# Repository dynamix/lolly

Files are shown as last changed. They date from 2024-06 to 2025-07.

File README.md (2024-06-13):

# lolly
Who does not like a LOLLY!

⠀⠀⠀⠀⠀⠀⠀⠀⠀⠀⠀⠀⠀⠀⠀⠀⠀⠀⠀⠀⠀⠀⠀⠀⠀⠀⠀⠀⠀⠀
⠀⠀⠀⠀⠀⠀⠀⠀⠀⠀⠀⠀⠀⠀⣀⣤⡶⠾⠿⠿⠷⠶⣦⣄⡀⠀⠀⠀⠀⠀
⠀⠀⠀⠀⠀⠀⠀⠀⠀⠀⠀⠀⣠⡾⠋⣁⣤⣶⣾⣿⣶⣦⣄⠙⠻⣦⡀⠀⠀⠀
⠀⠀⠀⠀⠀⠀⠀⠀⠀⠀⠀⣼⠟⢀⣾⣿⠟⠋⣉⣉⡉⠛⢿⣿⣄⠙⣷⡀⠀⠀
⠀⠀⠀⠀⠀⠀⠀⠀⠀⠀⢰⡟⢀⣿⡿⠁⣴⣿⠿⠿⣿⣶⡀⠻⣿⣇⢸⣇⠀⠀
⠀⠀⠀⠀⠀⠀⠀⠀⠀⠀⢸⡇⢸⣿⡇⢸⣿⡇⠀⣦⠈⢿⣿⠀⢻⣿⠀⣿⠀⠀
⠀⠀⠀⠀⠀⠀⠀⠀⠀⠀⠘⣧⠈⣿⣷⡀⠻⣿⣿⡿⢀⣾⣿⠀⣼⣿⠀⡏⠀⠀
⠀⠀⠀⠀⠀⠀⠀⠀⠀⠀⠀⢻⣆⠘⢿⣿⣦⣤⣠⣤⣾⡿⠋⣰⣿⡟⠘⠀⠀⠀
⠀⠀⠀⠀⠀⠀⠀⠀⠀⠀⢀⣄⠙⢷⣄⡉⠛⠿⠿⠛⠋⣠⣴⣿⠟⠀⠀⠀⠀⠀
⠀⠀⠀⠀⠀⠀⠀⠀⢀⣴⣿⠟⠀⠀⠉⠛⠓⠶⠶⠶⠿⠟⠛⠁⠀⠀⠀⠀⠀⠀
⠀⠀⠀⠀⠀⠀⢀⣴⣿⠟⠁⠀⠀⠀⠀⠀⠀⠀⠀⠀⠀⠀⠀⠀⠀⠀⠀⠀⠀⠀
⠀⠀⠀⠀⠀⣠⣿⠟⠁⠀⠀⠀⠀⠀⠀⠀⠀⠀⠀⠀⠀⠀⠀⠀⠀⠀⠀⠀⠀⠀
⠀⠀⠀⣠⣾⡿⠋⠀⠀⠀⠀⠀⠀⠀⠀⠀⠀⠀⠀⠀⠀⠀⠀⠀⠀⠀⠀⠀⠀⠀
⠀⠀⣼⠿⠋⠀⠀⠀⠀⠀⠀⠀⠀⠀⠀⠀⠀⠀⠀⠀⠀⠀⠀⠀⠀⠀⠀⠀⠀⠀
⠀⠀⠀⠀⠀⠀⠀⠀⠀⠀⠀⠀⠀⠀⠀⠀⠀⠀⠀⠀⠀⠀⠀⠀⠀⠀⠀⠀⠀⠀

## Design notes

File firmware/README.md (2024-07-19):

# L O L L Y

⠀⠀⠀⠀⠀⠀⠀⠀⠀⠀⠀⠀⠀⠀⠀⠀⠀⠀⠀⠀⠀⠀⠀⠀⠀⠀⠀⠀⠀⠀
⠀⠀⠀⠀⠀⠀⠀⠀⠀⠀⠀⠀⠀⠀⣀⣤⡶⠾⠿⠿⠷⠶⣦⣄⡀⠀⠀⠀⠀⠀
⠀⠀⠀⠀⠀⠀⠀⠀⠀⠀⠀⠀⣠⡾⠋⣁⣤⣶⣾⣿⣶⣦⣄⠙⠻⣦⡀⠀⠀⠀
⠀⠀⠀⠀⠀⠀⠀⠀⠀⠀⠀⣼⠟⢀⣾⣿⠟⠋⣉⣉⡉⠛⢿⣿⣄⠙⣷⡀⠀⠀
⠀⠀⠀⠀⠀⠀⠀⠀⠀⠀⢰⡟⢀⣿⡿⠁⣴⣿⠿⠿⣿⣶⡀⠻⣿⣇⢸⣇⠀⠀
⠀⠀⠀⠀⠀⠀⠀⠀⠀⠀⢸⡇⢸⣿⡇⢸⣿⡇⠀⣦⠈⢿⣿⠀⢻⣿⠀⣿⠀⠀
⠀⠀⠀⠀⠀⠀⠀⠀⠀⠀⠘⣧⠈⣿⣷⡀⠻⣿⣿⡿⢀⣾⣿⠀⣼⣿⠀⡏⠀⠀
⠀⠀⠀⠀⠀⠀⠀⠀⠀⠀⠀⢻⣆⠘⢿⣿⣦⣤⣠⣤⣾⡿⠋⣰⣿⡟⠘⠀⠀⠀
⠀⠀⠀⠀⠀⠀⠀⠀⠀⠀⢀⣄⠙⢷⣄⡉⠛⠿⠿⠛⠋⣠⣴⣿⠟⠀⠀⠀⠀⠀
⠀⠀⠀⠀⠀⠀⠀⠀⢀⣴⣿⠟⠀⠀⠉⠛⠓⠶⠶⠶⠿⠟⠛⠁⠀⠀⠀⠀⠀⠀
⠀⠀⠀⠀⠀⠀⢀⣴⣿⠟⠁⠀⠀⠀⠀⠀⠀⠀⠀⠀⠀⠀⠀⠀⠀⠀⠀⠀⠀⠀
⠀⠀⠀⠀⠀⣠⣿⠟⠁⠀⠀⠀⠀⠀⠀⠀⠀⠀⠀⠀⠀⠀⠀⠀⠀⠀⠀⠀⠀⠀
⠀⠀⠀⣠⣾⡿⠋⠀⠀⠀⠀⠀⠀⠀⠀⠀⠀⠀⠀⠀⠀⠀⠀⠀⠀⠀⠀⠀⠀⠀
⠀⠀⣼⠿⠋⠀⠀⠀⠀⠀⠀⠀⠀⠀⠀⠀⠀⠀⠀⠀⠀⠀⠀⠀⠀⠀⠀⠀⠀⠀
⠀⠀⠀⠀⠀⠀⠀⠀⠀⠀⠀⠀⠀⠀⠀⠀⠀⠀⠀⠀⠀⠀⠀⠀⠀⠀⠀

Lick it! Get electroCUTEd!

## Prerequisites

- [Arduino 2.3.2](https://www.arduino.cc/en/Main/Software?)
- `brew install arduino-cli` might be enough
- [latest Teensyduino](https://www.pjrc.com/teensy/td_download.html)
  - add this to "Additional board manager URLs" in Arduino settings:
  - `https://www.pjrc.com/teensy/package_teensy_index.json`
- a Teensy 3.6
- a RaspperyPi Zero W (for over the air updates)

## Setup

Get the `teensy_loader_cli` available in the repo `firmware` directory:
```bash
cd firmware
brew install teensy_loader_cli
ln -s $(which teensy_loader_cli) ./teensy_loader_cli 
```

### Needed libraries

To make it easier - every lib including the Teensy core are in this repo :) 

**Important** for the potentiometer to work correctly, the Teensy Audio library needed to be edited
. Open `input_adc.cpp` (to be found in the Teensy audio library folder) and find the call to `analogReference(INTERNAL);` and comment it out. (See https://github.com/PaulStoffregen/Audio/blob/master/input_adc.cpp#L51)

# Simulator

Check out: https://wokwi.com/projects/403018840445060097

# Remark

The code base is in no way idiomatic C/C++ (i.e. directly including files without headers) or written to please the eye. :-)

# Build

```
make
```

# Deploy

Over the air deployment relies on:
- the PI is connected to the local network
- the PI and the Teensy are correctly connected
- the teensyloader is available on the PI

```
make deploy
```

# Serial port on Pi

TODO

# Ideas for effects

* animation going for inside to the outside
* circles from mid to edge rotating at different speeds with diff
* spirals controllable with knobs and buttons
* classic lolly spirals red and white with one arm or many
* Bitmap/GIF rendering! For a smily or a heart
* a pulsing heart
* color sparkels
* fire
* plasma
* bouncy balls
* rains
* audio wave form visualisation
* little particles going in a direction that start with very white light and fade after

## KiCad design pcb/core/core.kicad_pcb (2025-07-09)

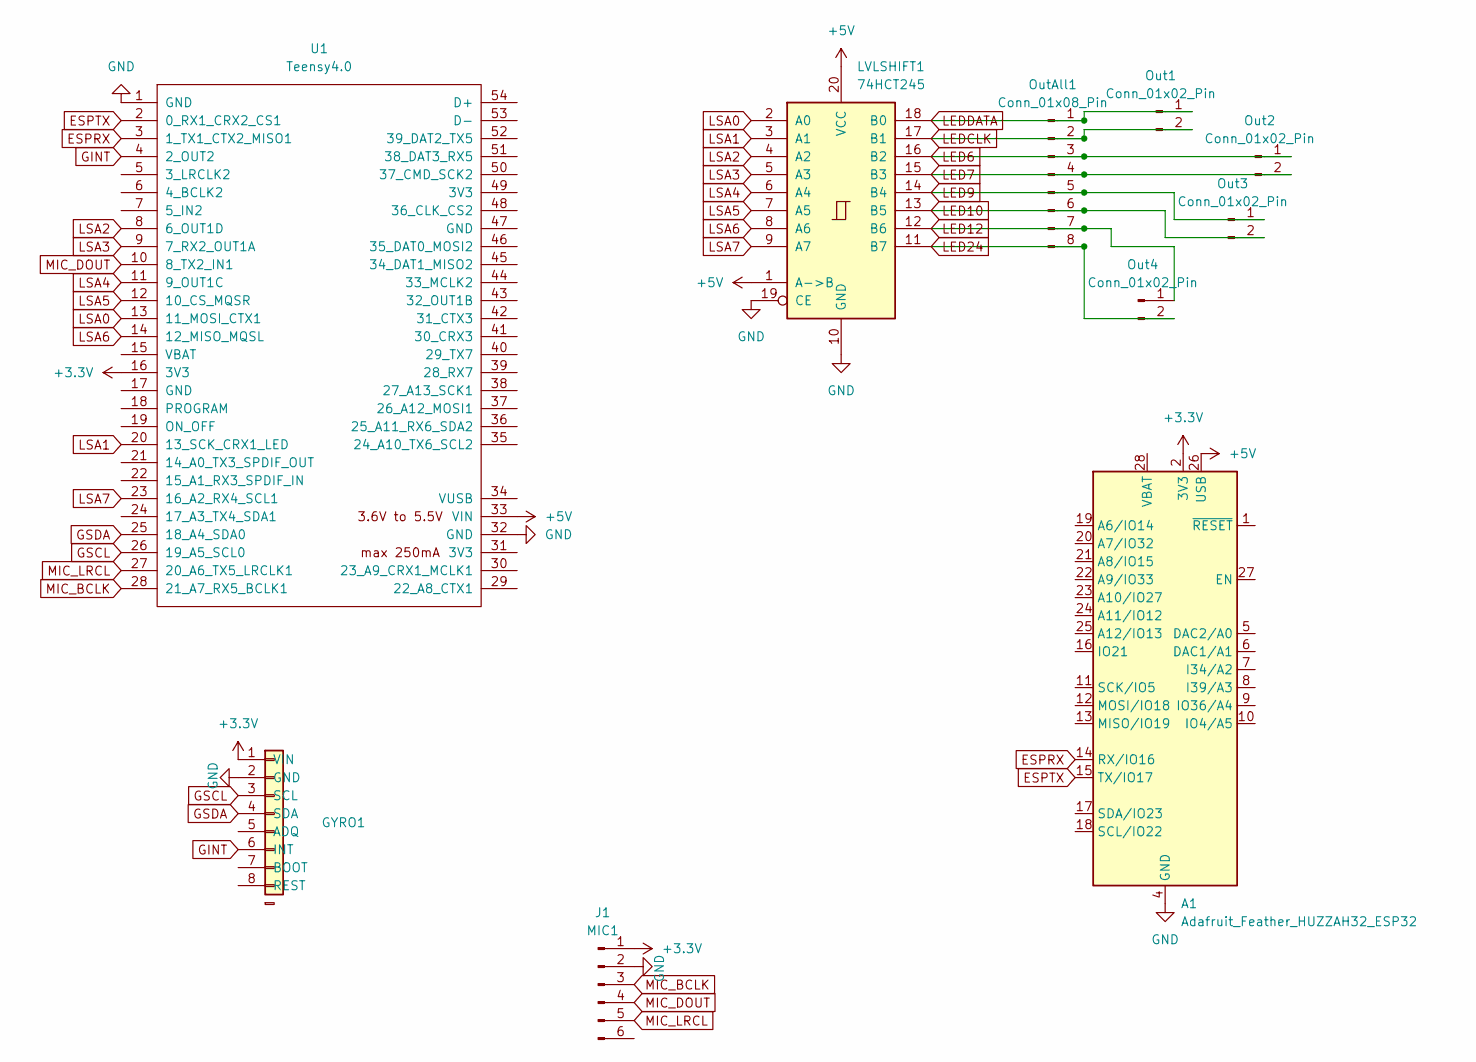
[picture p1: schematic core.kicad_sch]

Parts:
A1: Adafruit_Feather_HUZZAH32_ESP32; Adafruit_Feather
GYRO1: Conn_01x09; PinHeader_1x08_P2.54mm_Vertical
J1: MIC1; PinHeader_1x06_P2.54mm_Vertical
LVLSHIFT1: 74HCT245; SOIC-20W_7.5x12.8mm_P1.27mm
Out1, Out2, Out3, Out4: Conn_01x02_Pin; JST_PH_B2B-PH-K_1x02_P2.00mm_Vertical
OutAll1: Conn_01x08_Pin; PinHeader_1x08_P2.54mm_Vertical
U1: Teensy4.0; Teensy40

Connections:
+3.3V: A1.2 (3V3), GYRO1.1 (VIN), J1.1, U1.16 (3V3)
+5V: A1.26 (USB), LVLSHIFT1.1 (A->B), LVLSHIFT1.20 (VCC), U1.33 (VIN)
ESPRX: A1.14 (RX/IO16), U1.3 (1_TX1_CTX2_MISO1)
ESPTX: A1.15 (TX/IO17), U1.2 (0_RX1_CRX2_CS1)
GINT: GYRO1.6 (INT), U1.4 (2_OUT2)
GND: A1.4 (GND), GYRO1.2 (GND), J1.2, LVLSHIFT1.10 (GND), LVLSHIFT1.19 (CE), U1.1 (GND), U1.32 (GND)
GSCL: GYRO1.3 (SCL), U1.26 (19_A5_SCL0)
GSDA: GYRO1.4 (SDA), U1.25 (18_A4_SDA0)
LED6: LVLSHIFT1.16 (B2), Out2.1, OutAll1.3
LED7: LVLSHIFT1.15 (B3), Out2.2, OutAll1.4
LED9: LVLSHIFT1.14 (B4), Out3.1, OutAll1.5
LED10: LVLSHIFT1.13 (B5), Out3.2, OutAll1.6
LED12: LVLSHIFT1.12 (B6), Out4.1, OutAll1.7
LED24: LVLSHIFT1.11 (B7), Out4.2, OutAll1.8
LEDCLK: LVLSHIFT1.17 (B1), Out1.2, OutAll1.2
LEDDATA: LVLSHIFT1.18 (B0), Out1.1, OutAll1.1
LSA0: LVLSHIFT1.2 (A0), U1.13 (11_MOSI_CTX1)
LSA1: LVLSHIFT1.3 (A1), U1.20 (13_SCK_CRX1_LED)
LSA2: LVLSHIFT1.4 (A2), U1.8 (6_OUT1D)
LSA3: LVLSHIFT1.5 (A3), U1.9 (7_RX2_OUT1A)
LSA4: LVLSHIFT1.6 (A4), U1.11 (9_OUT1C)
LSA5: LVLSHIFT1.7 (A5), U1.12 (10_CS_MQSR)
LSA6: LVLSHIFT1.8 (A6), U1.14 (12_MISO_MQSL)
LSA7: LVLSHIFT1.9 (A7), U1.23 (16_A2_RX4_SCL1)
MIC_BCLK: J1.3, U1.28 (21_A7_RX5_BCLK1)
MIC_DOUT: J1.4, U1.10 (8_TX2_IN1)
MIC_LRCL: J1.5, U1.27 (20_A6_TX5_LRCLK1)

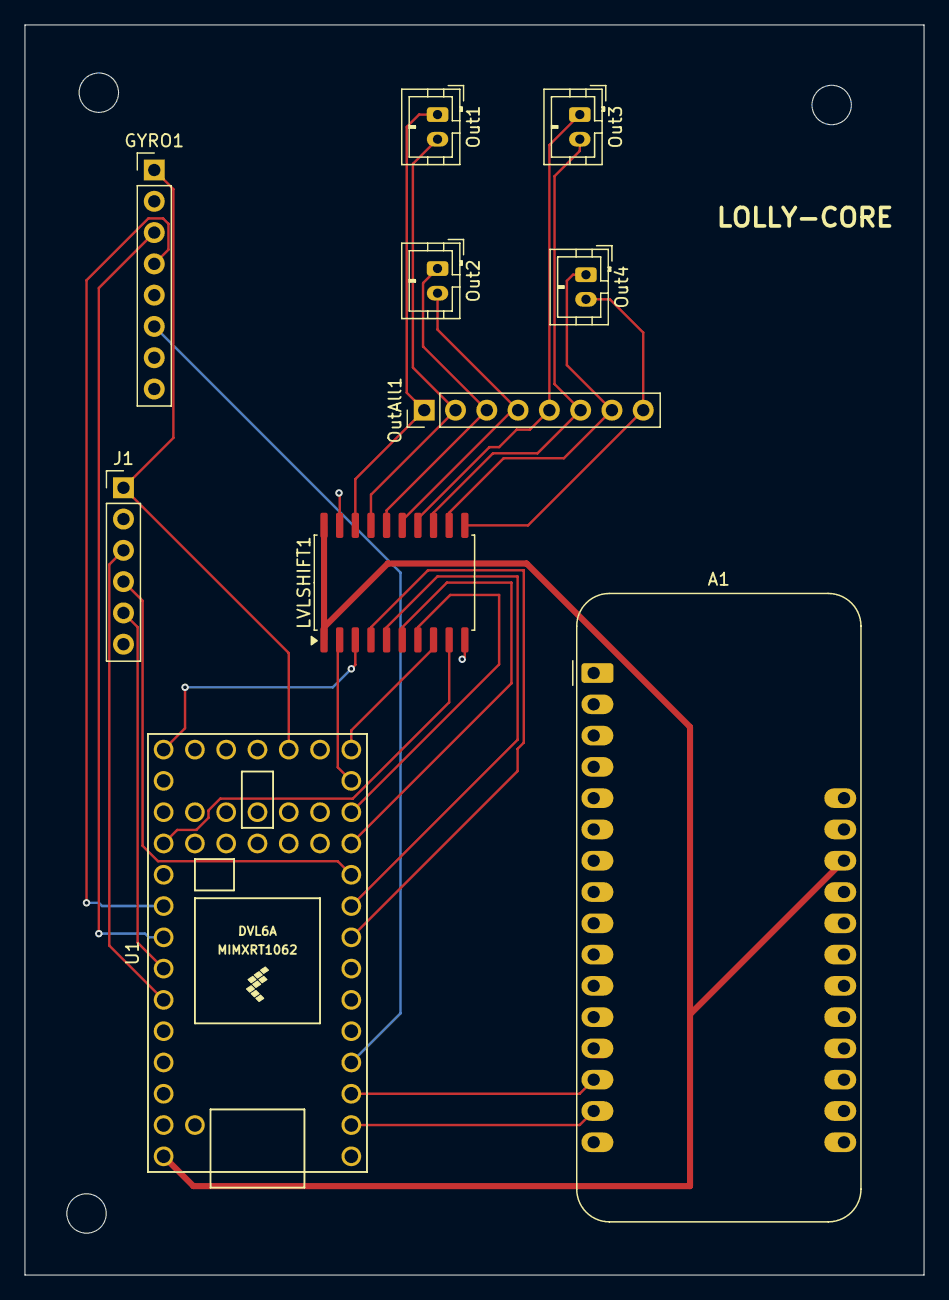
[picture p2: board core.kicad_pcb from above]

Board: 2 copper layers, 73.0 x 101.5 mm, 10 parts (0 on the bottom side), 27 nets.

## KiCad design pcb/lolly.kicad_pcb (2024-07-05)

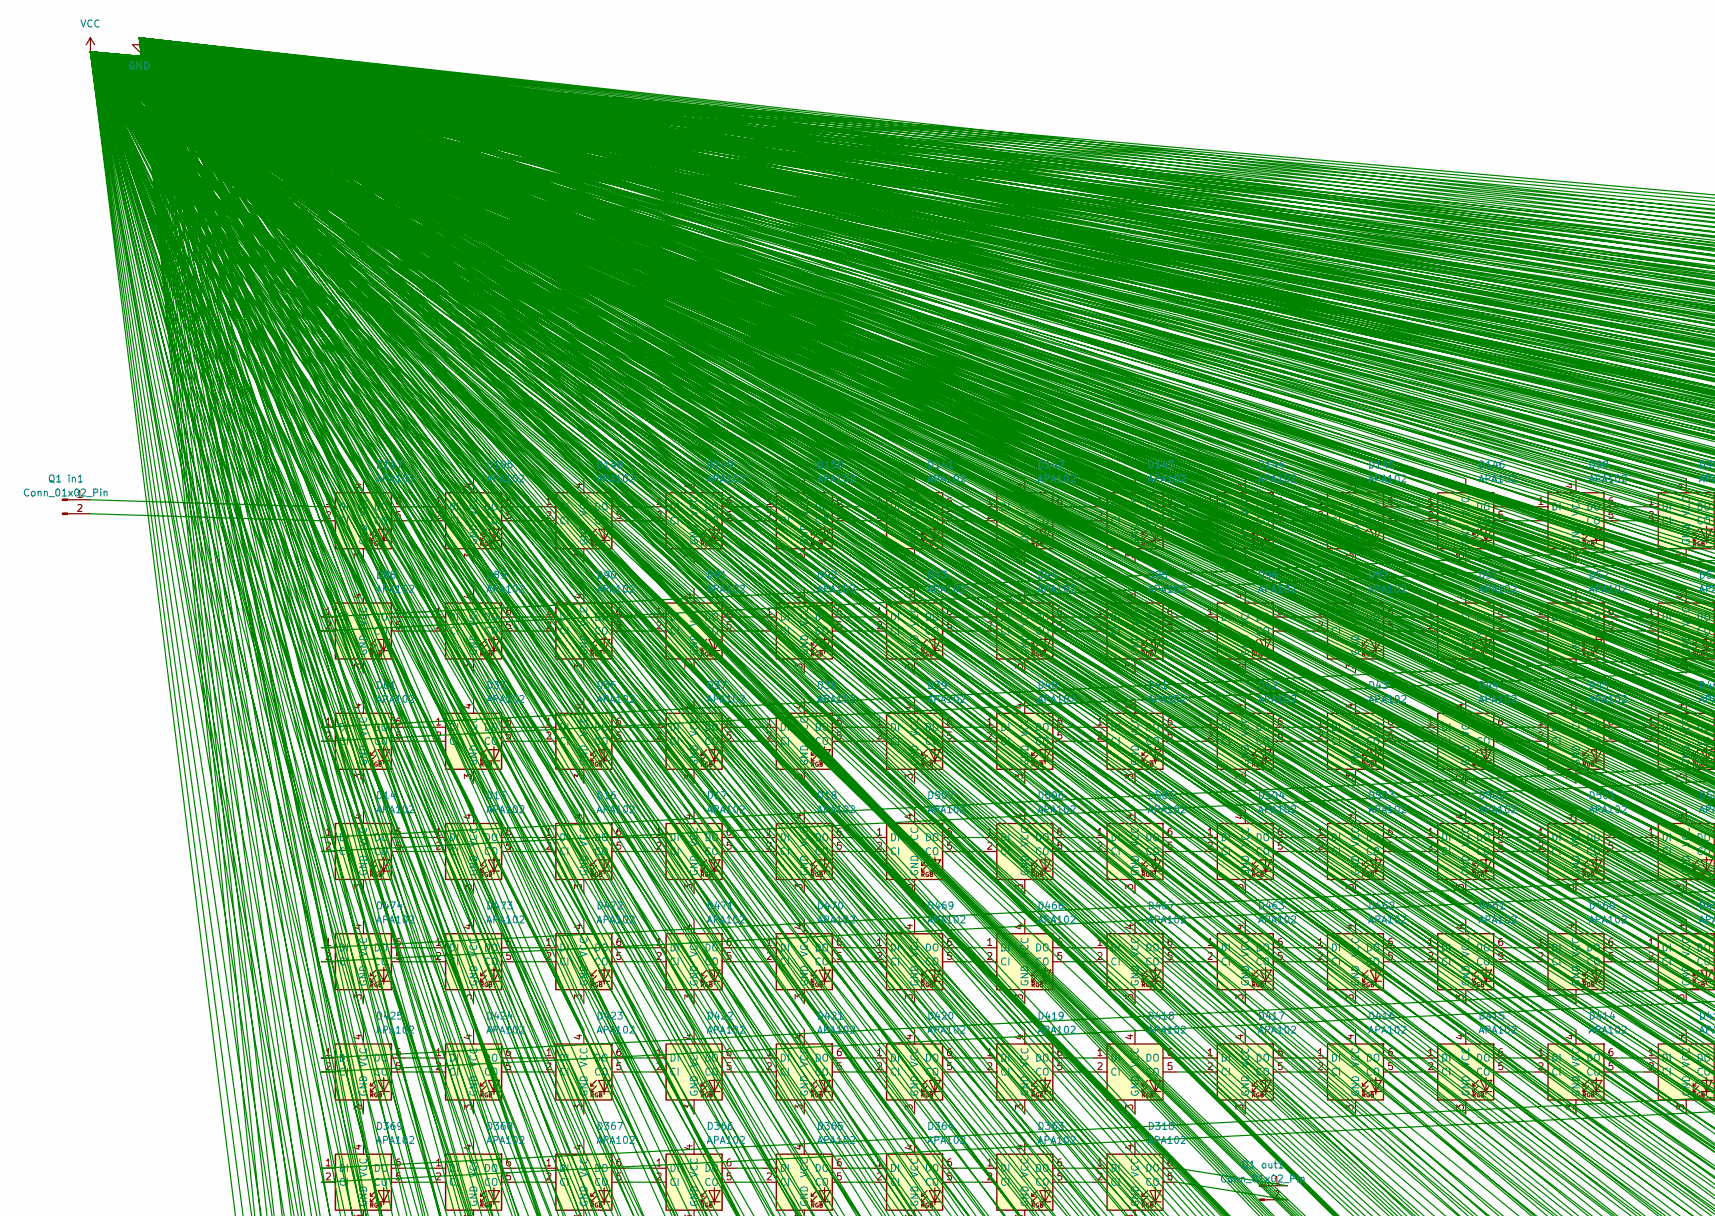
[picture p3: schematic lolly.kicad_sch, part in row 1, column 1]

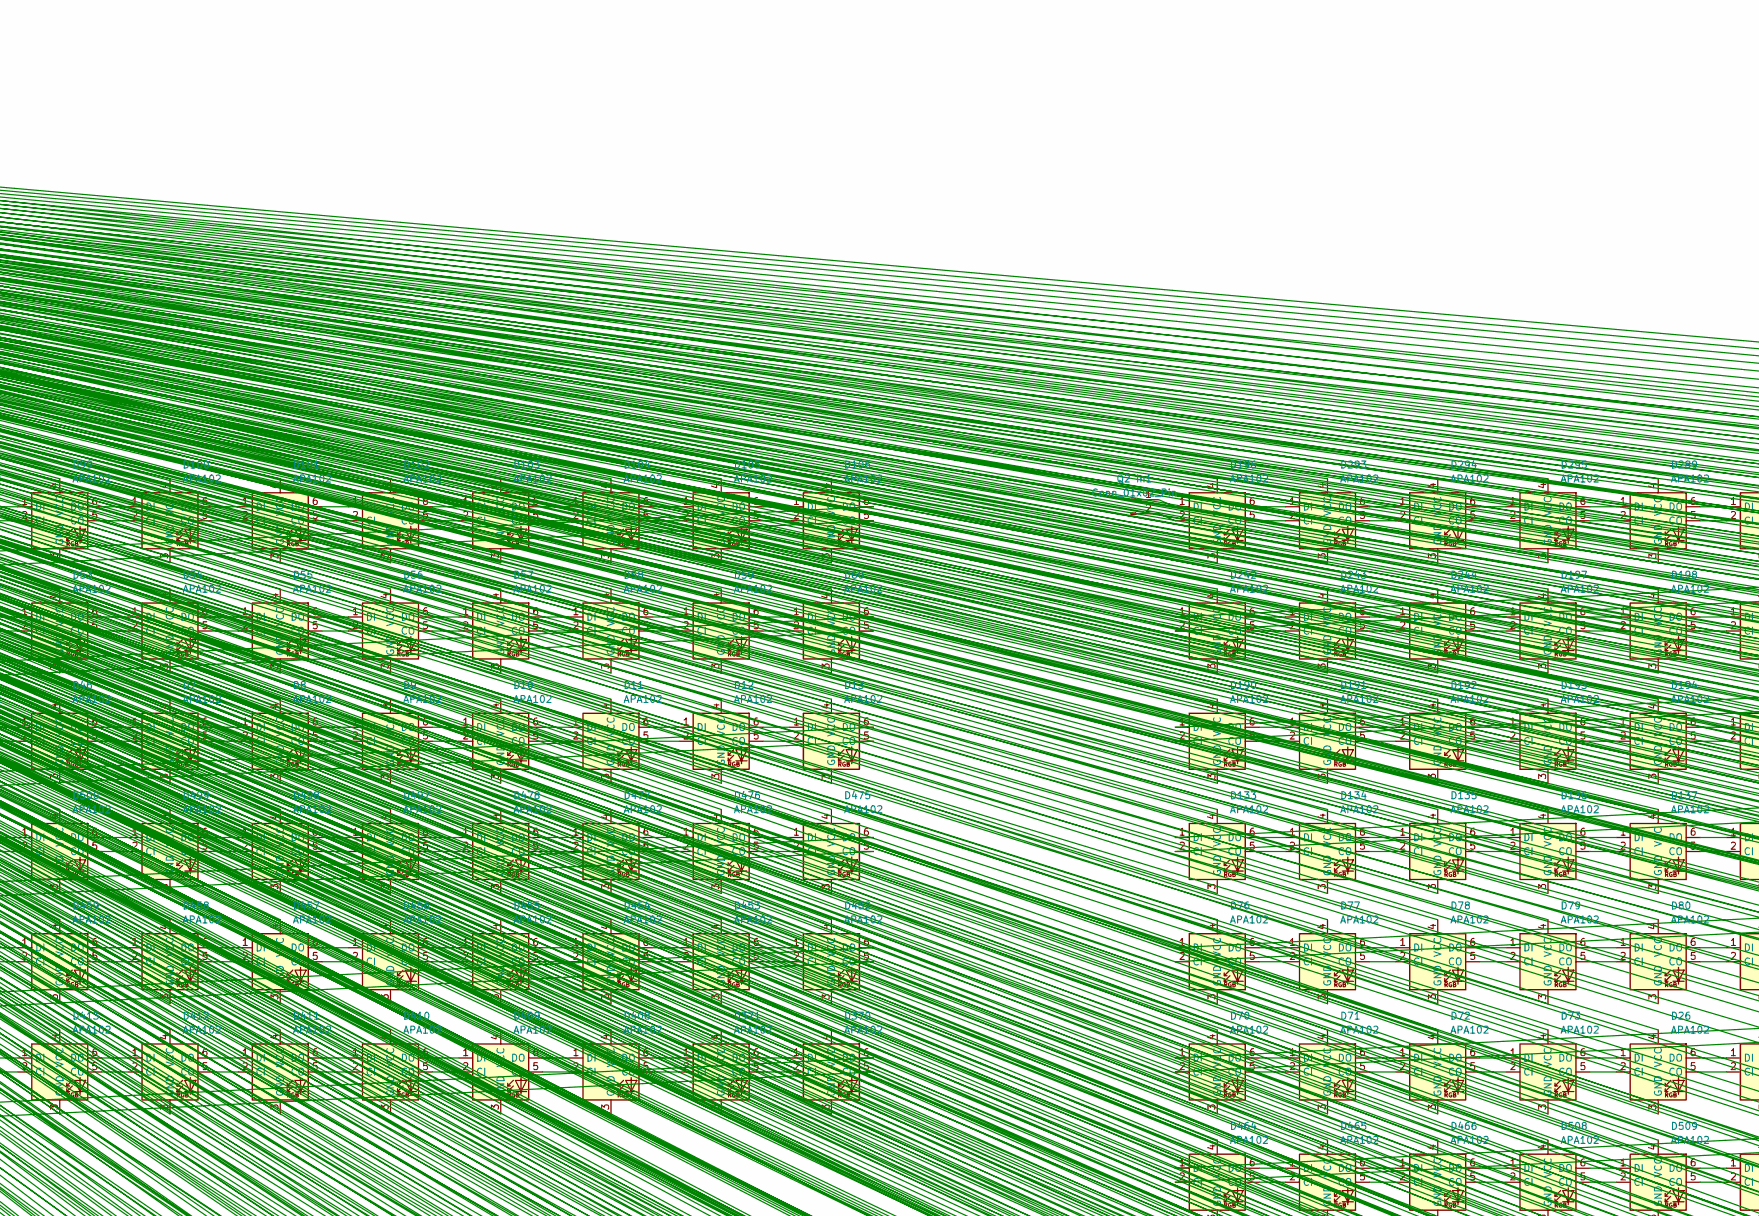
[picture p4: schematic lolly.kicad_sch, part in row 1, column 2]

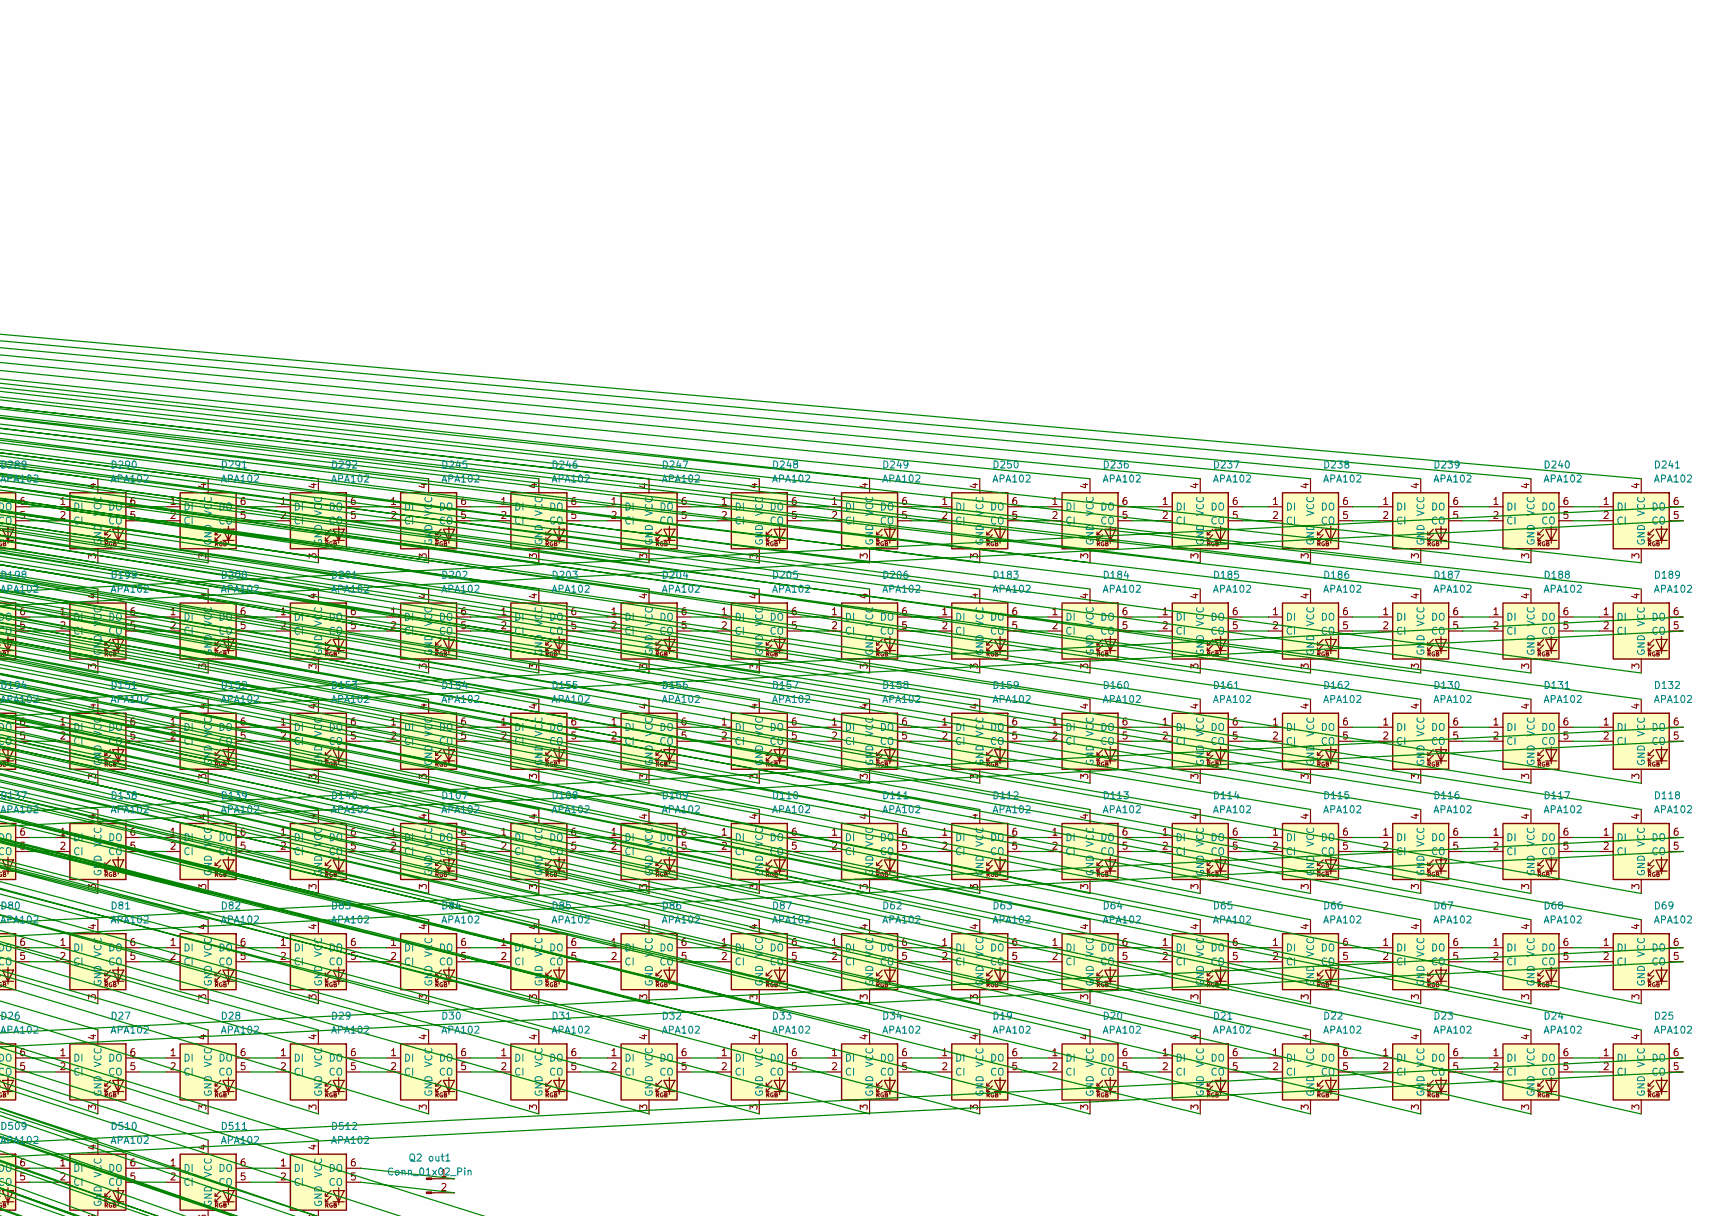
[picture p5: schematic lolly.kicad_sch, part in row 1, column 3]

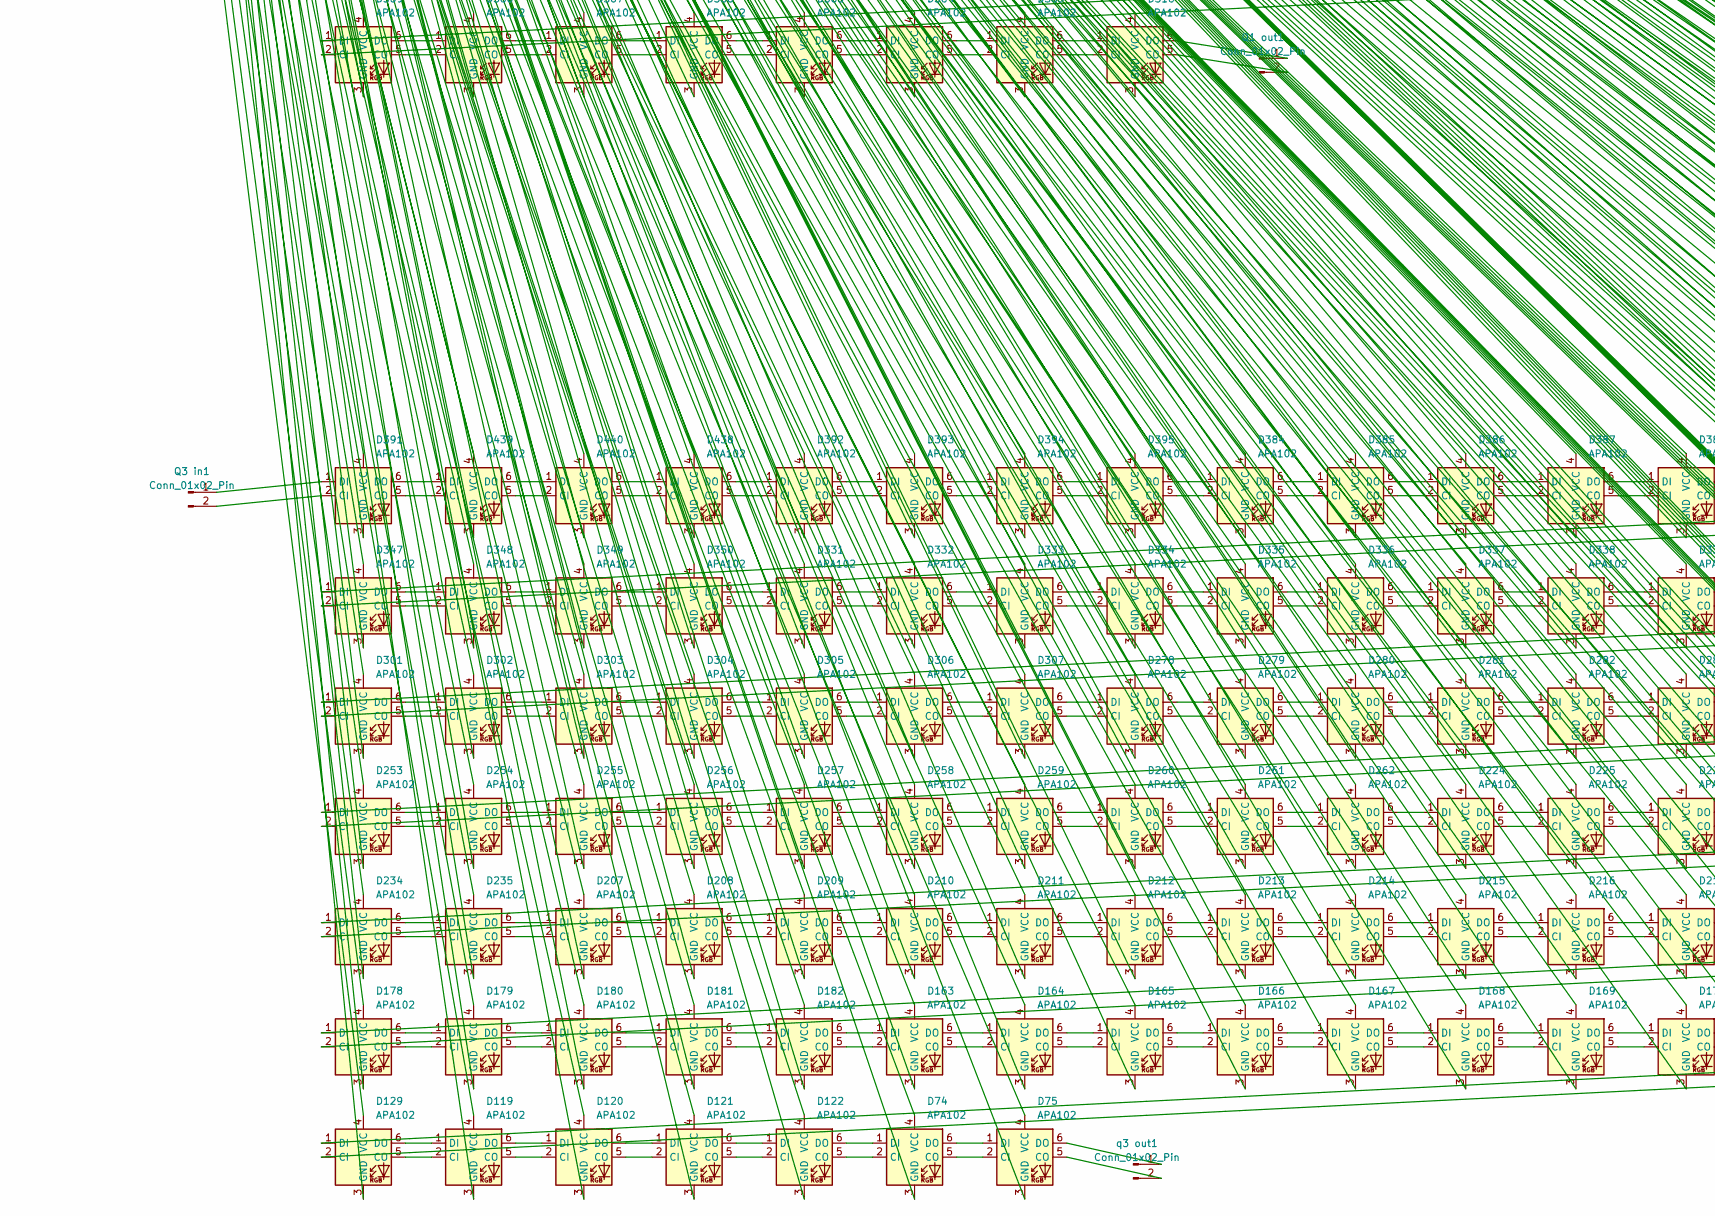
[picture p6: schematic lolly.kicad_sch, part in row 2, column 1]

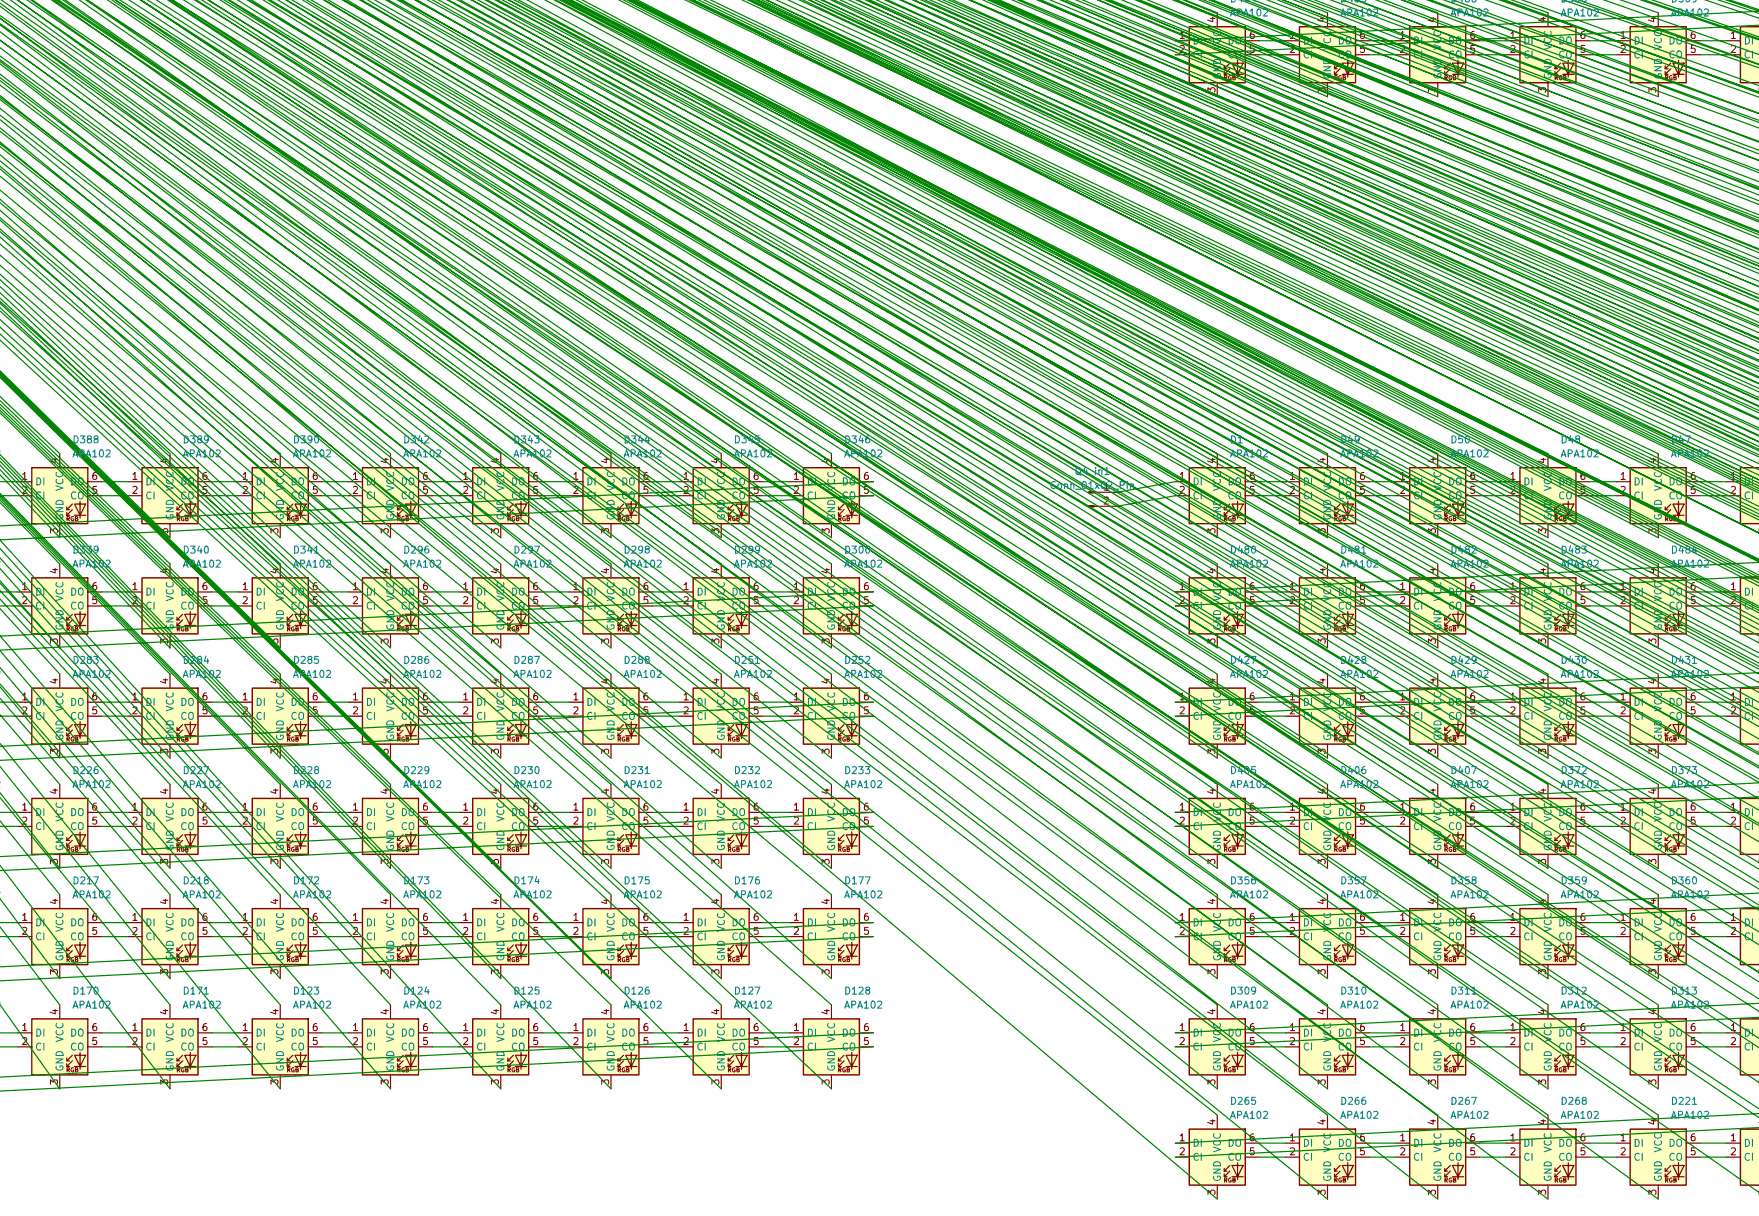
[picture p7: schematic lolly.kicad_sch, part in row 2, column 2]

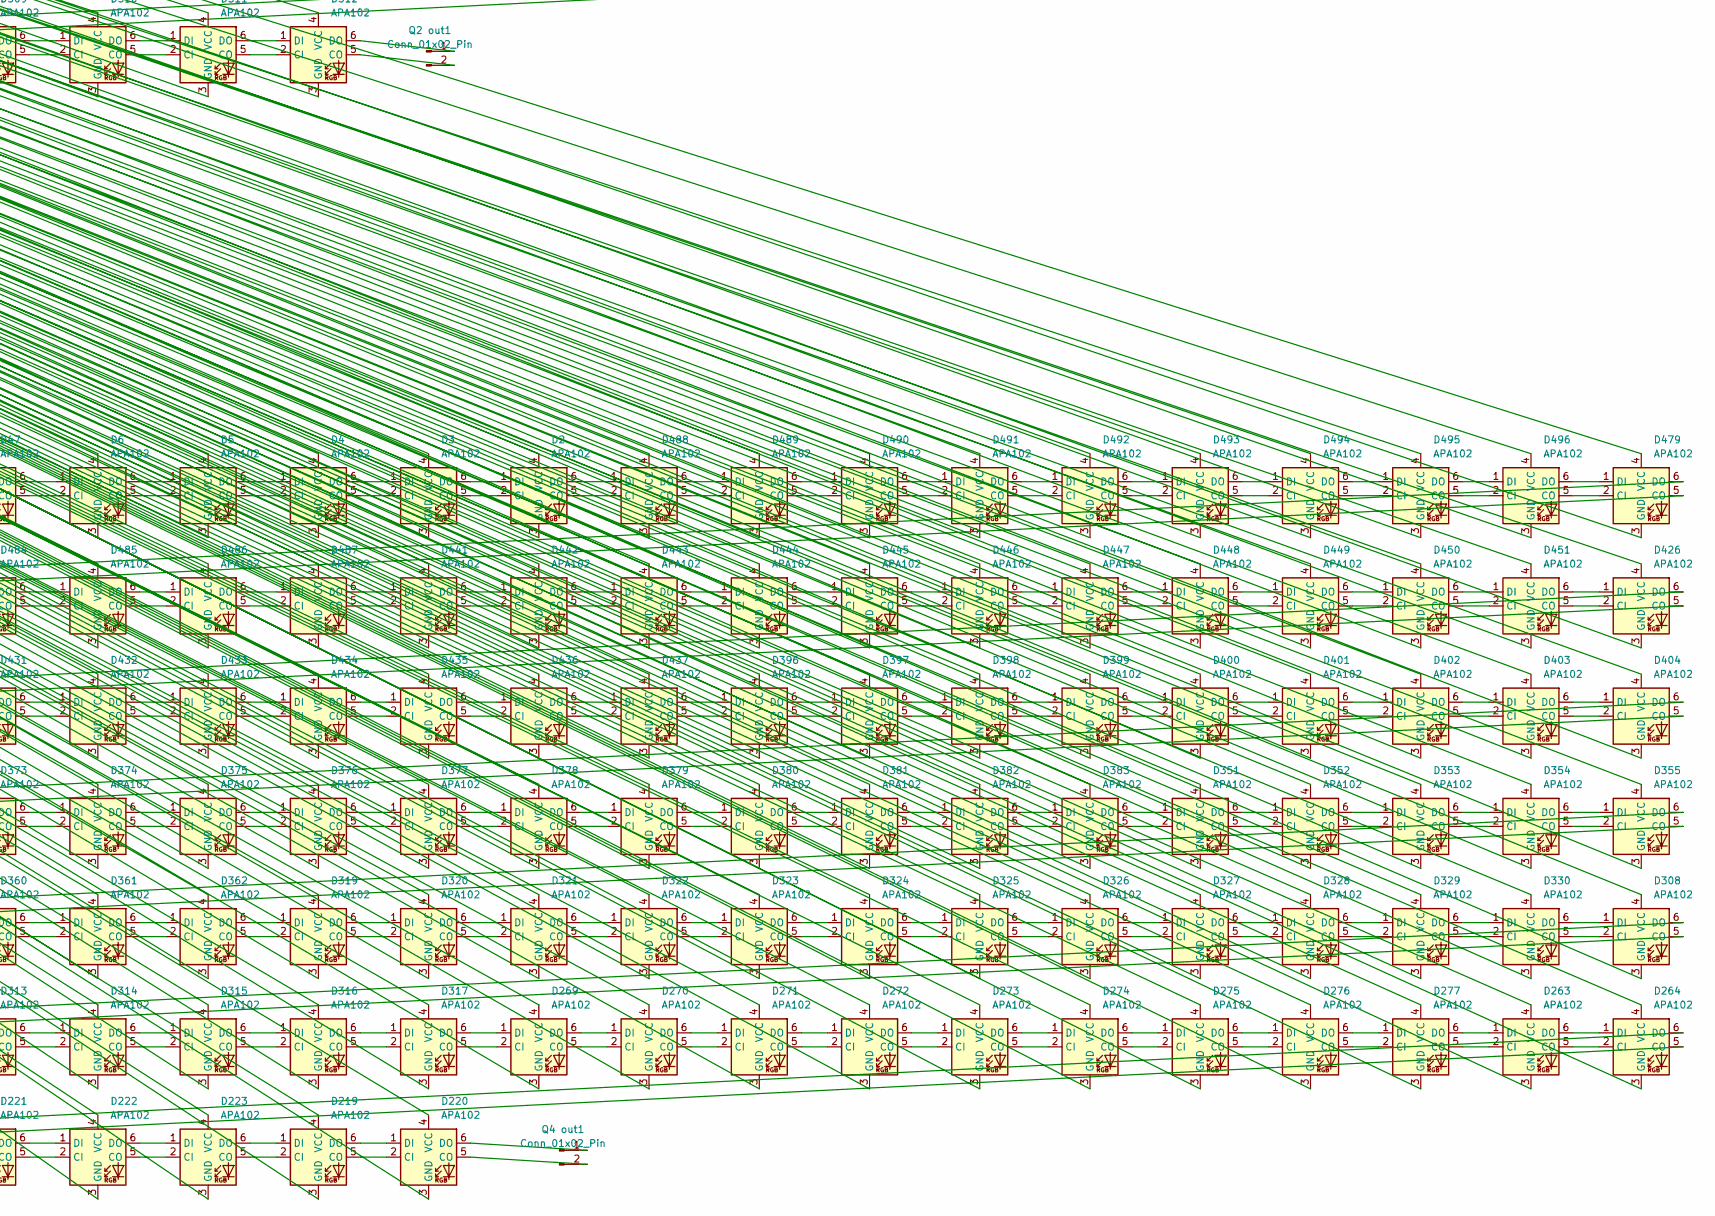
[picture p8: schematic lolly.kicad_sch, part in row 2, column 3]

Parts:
D1, D2, D3, D4, D5, D6, D7, D8, D9, D10, D11, D12, D13, D14, D15, D16, D17, D18, D19, D20, D21, D22, D23, D24, D25, D26, D27, D28, D29, D30, D31, D32, D33, D34, D35, D36, D37, D38, D39, D40, D41, D42, D43, D44, D45, D46, D47, D48, D49, D50, D51, D52, D53, D54, D55, D56, D57, D58, D59, D60, D61, D62, D63, D64, D65, D66, D67, D68, D69, D70, D71, D72, D73, D74, D75, D76, D77, D78, D79, D80, D81, D82, D83, D84, D85, D86, D87, D88, D89, D90, D91, D92, D93, D94, D95, D96, D97, D98, D99, D100, D101, D102, D103, D104, D105, D106, D107, D108, D109, D110, D111, D112, D113, D114, D115, D116, D117, D118, D119, D120, D121, D122, D123, D124, D125, D126, D127, D128, D129, D130, D131, D132, D133, D134, D135, D136, D137, D138, D139, D140, D141, D142, D143, D144, D145, D146, D147, D148, D149, D150, D151, D152, D153, D154, D155, D156, D157, D158, D159, D160, D161, D162, D163, D164, D165, D166, D167, D168, D169, D170, D171, D172, D173, D174, D175, D176, D177, D178, D179, D180, D181, D182, D183, D184, D185, D186, D187, D188, D189, D190, D191, D192, D193, D194, D195, D196, D197, D198, D199, D200, D201, D202, D203, D204, D205, D206, D207, D208, D209, D210, D211, D212, D213, D214, D215, D216, D217, D218, D219, D220, D221, D222, D223, D224, D225, D226, D227, D228, D229, D230, D231, D232, D233, D234, D235, D236, D237, D238, D239, D240, D241, D242, D243, D244, D245, D246, D247, D248, D249, D250, D251, D252, D253, D254, D255, D256, D257, D258, D259, D260, D261, D262, D263, D264, D265, D266, D267, D268, D269, D270, D271, D272, D273, D274, D275, D276, D277, D278, D279, D280, D281, D282, D283, D284, D285, D286, D287, D288, D289, D290, D291, D292, D293, D294, D295, D296, D297, D298, D299, D300, D301, D302, D303, D304, D305, D306, D307, D308, D309, D310, D311, D312, D313, D314, D315, D316, D317, D318, D319, D320, D321, D322, D323, D324, D325, D326, D327, D328, D329, D330, D331, D332, D333, D334, D335, D336, D337, D338, D339, D340, D341, D342, D343, D344, D345, D346, D347, D348, D349, D350, D351, D352, D353, D354, D355, D356, D357, D358, D359, D360, D361, D362, D363, D364, D365, D366, D367, D368, D369, D370, D371, D372, D373, D374, D375, D376, D377, D378, D379, D380, D381, D382, D383, D384, D385, D386, D387, D388, D389, D390, D391, D392, D393, D394, D395, D396, D397, D398, D399, D400, D401, D402, D403, D404, D405, D406, D407, D408, D409, D410, D411, D412, D413, D414, D415, D416, D417, D418, D419, D420, D421, D422, D423, D424, D425, D426, D427, D428, D429, D430, D431, D432, D433, D434, D435, D436, D437, D438, D439, D440, D441, D442, D443, D444, D445, D446, D447, D448, D449, D450, D451, D452, D453, D454, D455, D456, D457, D458, D459, D460, D461, D462, D463, D464, D465, D466, D467, D468, D469, D470, D471, D472, D473, D474, D475, D476, D477, D478, D479, D480, D481, D482, D483, D484, D485, D486, D487, D488, D489, D490, D491, D492, D493, D494, D495, D496, D497, D498, D499, D500, D501, D502, D503, D504, D505, D506, D507, D508, D509, D510, D511, D512: APA102; LED_RGB_5050-6
Q1 in1, Q1 out1, Q2 in1, Q2 out1, Q3 in1, Q4 in1, Q4 out1: Conn_01x02_Pin; JST_PH_B2B-PH-K_1x02_P2.00mm_Vertical
q3 out1: Conn_01x02_Pin; JST_PH_B2B-PH-K_1x02_P2.00mm_Vertical

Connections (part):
GND: D1.3 (GND), D2.3 (GND), D3.3 (GND), D4.3 (GND), D5.3 (GND), D6.3 (GND), D7.3 (GND), D8.3 (GND), D9.3 (GND), D10.3 (GND), D11.3 (GND), D12.3 (GND), D13.3 (GND), D14.3 (GND), D15.3 (GND), D16.3 (GND), D17.3 (GND), D18.3 (GND), D19.3 (GND), D20.3 (GND), D21.3 (GND), D22.3 (GND), D23.3 (GND), D24.3 (GND), D25.3 (GND), D26.3 (GND), D27.3 (GND), D28.3 (GND), D29.3 (GND), D30.3 (GND), D31.3 (GND), D32.3 (GND), D33.3 (GND), D34.3 (GND), D35.3 (GND), D36.3 (GND), D37.3 (GND), D38.3 (GND), D39.3 (GND), D40.3 (GND), D41.3 (GND), D42.3 (GND), D43.3 (GND), D44.3 (GND), D45.3 (GND), D46.3 (GND), D47.3 (GND), D48.3 (GND), D49.3 (GND), D50.3 (GND), D51.3 (GND), D52.3 (GND), D53.3 (GND), D54.3 (GND), D55.3 (GND), D56.3 (GND), D57.3 (GND), D58.3 (GND), D59.3 (GND), D60.3 (GND), D61.3 (GND), D62.3 (GND), D63.3 (GND), D64.3 (GND), D65.3 (GND), D66.3 (GND), D67.3 (GND), D68.3 (GND), D69.3 (GND), D70.3 (GND), D71.3 (GND), D72.3 (GND), D73.3 (GND), D74.3 (GND), D75.3 (GND), D76.3 (GND), D77.3 (GND), D78.3 (GND), D79.3 (GND), D80.3 (GND)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; also elsewhere on the board
unnamed: D1.2 (CI), Q4 in1.2
unnamed: D1.5 (CO), D49.2 (CI)
unnamed: D1.1 (DI), Q4 in1.1
unnamed: D1.6 (DO), D49.1 (DI)
unnamed: D2.2 (CI), D3.5 (CO)
unnamed: D2.5 (CO), D488.2 (CI)
unnamed: D2.1 (DI), D3.6 (DO)
unnamed: D2.6 (DO), D488.1 (DI)
unnamed: D3.2 (CI), D4.5 (CO)
unnamed: D3.1 (DI), D4.6 (DO)
unnamed: D4.2 (CI), D5.5 (CO)
unnamed: D4.1 (DI), D5.6 (DO)
unnamed: D5.2 (CI), D6.5 (CO)
unnamed: D5.1 (DI), D6.6 (DO)
unnamed: D7.5 (CO), D8.2 (CI)
unnamed: D7.6 (DO), D8.1 (DI)
unnamed: D8.5 (CO), D9.2 (CI)
unnamed: D8.6 (DO), D9.1 (DI)
unnamed: D9.5 (CO), D10.2 (CI)
unnamed: D10.5 (CO), D11.2 (CI)
unnamed: D9.6 (DO), D10.1 (DI)
unnamed: D10.6 (DO), D11.1 (DI)
unnamed: D11.5 (CO), D12.2 (CI)
unnamed: D11.6 (DO), D12.1 (DI)
unnamed: D12.5 (CO), D13.2 (CI)
unnamed: D12.6 (DO), D13.1 (DI)
unnamed: D13.5 (CO), D14.2 (CI)
unnamed: D13.6 (DO), D14.1 (DI)
unnamed: D14.5 (CO), D15.2 (CI)
unnamed: D14.6 (DO), D15.1 (DI)
unnamed: D15.5 (CO), D16.2 (CI)
unnamed: D15.6 (DO), D16.1 (DI)
unnamed: D16.5 (CO), D17.2 (CI)
unnamed: D16.6 (DO), D17.1 (DI)
unnamed: D17.5 (CO), D18.2 (CI)
unnamed: D17.6 (DO), D18.1 (DI)
unnamed: D18.5 (CO), D507.2 (CI)
unnamed: D18.6 (DO), D507.1 (DI)
unnamed: D19.2 (CI), D34.5 (CO)
unnamed: D19.5 (CO), D20.2 (CI)
unnamed: D19.1 (DI), D34.6 (DO)
unnamed: D19.6 (DO), D20.1 (DI)
unnamed: D20.5 (CO), D21.2 (CI)
unnamed: D20.6 (DO), D21.1 (DI)
unnamed: D21.5 (CO), D22.2 (CI)
unnamed: D21.6 (DO), D22.1 (DI)
unnamed: D22.5 (CO), D23.2 (CI)
unnamed: D22.6 (DO), D23.1 (DI)
unnamed: D23.5 (CO), D24.2 (CI)
unnamed: D23.6 (DO), D24.1 (DI)
unnamed: D24.5 (CO), D25.2 (CI)
unnamed: D24.6 (DO), D25.1 (DI)
unnamed: D25.5 (CO), D464.2 (CI)
unnamed: D25.6 (DO), D464.1 (DI)
unnamed: D26.2 (CI), D73.5 (CO)
unnamed: D26.5 (CO), D27.2 (CI)
unnamed: D26.1 (DI), D73.6 (DO)
unnamed: D26.6 (DO), D27.1 (DI)
unnamed: D27.5 (CO), D28.2 (CI)
unnamed: D27.6 (DO), D28.1 (DI)
unnamed: D28.5 (CO), D29.2 (CI)
unnamed: D28.6 (DO), D29.1 (DI)
unnamed: D29.5 (CO), D30.2 (CI)
unnamed: D29.6 (DO), D30.1 (DI)
unnamed: D30.5 (CO), D31.2 (CI)
unnamed: D30.6 (DO), D31.1 (DI)
unnamed: D31.5 (CO), D32.2 (CI)
unnamed: D31.6 (DO), D32.1 (DI)
unnamed: D32.5 (CO), D33.2 (CI)
unnamed: D32.6 (DO), D33.1 (DI)
unnamed: D33.5 (CO), D34.2 (CI)
unnamed: D33.6 (DO), D34.1 (DI)
unnamed: D35.2 (CI), D61.5 (CO)
unnamed: D35.5 (CO), D36.2 (CI)
unnamed: D35.1 (DI), D61.6 (DO)
unnamed: D35.6 (DO), D36.1 (DI)
unnamed: D36.5 (CO), D37.2 (CI)
unnamed: D36.6 (DO), D37.1 (DI)
unnamed: D37.5 (CO), D38.2 (CI)
unnamed: D37.6 (DO), D38.1 (DI)
unnamed: D38.5 (CO), D39.2 (CI)
unnamed: D38.6 (DO), D39.1 (DI)
unnamed: D39.5 (CO), D40.2 (CI)
unnamed: D39.6 (DO), D40.1 (DI)
unnamed: D40.5 (CO), D41.2 (CI)
unnamed: D40.6 (DO), D41.1 (DI)
unnamed: D41.5 (CO), D42.2 (CI)
unnamed: D41.6 (DO), D42.1 (DI)
unnamed: D42.5 (CO), D43.2 (CI)
unnamed: D42.6 (DO), D43.1 (DI)
unnamed: D43.5 (CO), D44.2 (CI)
unnamed: D43.6 (DO), D44.1 (DI)
unnamed: D44.5 (CO), D45.2 (CI)
unnamed: D44.6 (DO), D45.1 (DI)
unnamed: D45.5 (CO), D46.2 (CI)
unnamed: D45.6 (DO), D46.1 (DI)
unnamed: D7.2 (CI), D46.5 (CO)
unnamed: D7.1 (DI), D46.6 (DO)
unnamed: D47.2 (CI), D48.5 (CO)
unnamed: D6.2 (CI), D47.5 (CO)
unnamed: D47.1 (DI), D48.6 (DO)
unnamed: D6.1 (DI), D47.6 (DO)
unnamed: D48.2 (CI), D50.5 (CO)
unnamed: D48.1 (DI), D50.6 (DO)
unnamed: D49.5 (CO), D50.2 (CI)
unnamed: D49.6 (DO), D50.1 (DI)
unnamed: D51.2 (CI), D97.5 (CO)
unnamed: D51.5 (CO), D52.2 (CI)
unnamed: D51.1 (DI), D97.6 (DO)
unnamed: D51.6 (DO), D52.1 (DI)
unnamed: D52.5 (CO), D53.2 (CI)
unnamed: D52.6 (DO), D53.1 (DI)
unnamed: D53.5 (CO), D54.2 (CI)
unnamed: D53.6 (DO), D54.1 (DI)
unnamed: D54.5 (CO), D55.2 (CI)
unnamed: D54.6 (DO), D55.1 (DI)
unnamed: D55.5 (CO), D56.2 (CI)
unnamed: D55.6 (DO), D56.1 (DI)
unnamed: D56.5 (CO), D57.2 (CI)
unnamed: D56.6 (DO), D57.1 (DI)
unnamed: D57.5 (CO), D58.2 (CI)
unnamed: D57.6 (DO), D58.1 (DI)
unnamed: D58.5 (CO), D59.2 (CI)
unnamed: D58.6 (DO), D59.1 (DI)
unnamed: D59.5 (CO), D60.2 (CI)
unnamed: D59.6 (DO), D60.1 (DI)
unnamed: D60.5 (CO), D61.2 (CI)
unnamed: D60.6 (DO), D61.1 (DI)
unnamed: D62.2 (CI), D87.5 (CO)
unnamed: D62.5 (CO), D63.2 (CI)
unnamed: D62.1 (DI), D87.6 (DO)
unnamed: D62.6 (DO), D63.1 (DI)
unnamed: D63.5 (CO), D64.2 (CI)
unnamed: D63.6 (DO), D64.1 (DI)
unnamed: D64.5 (CO), D65.2 (CI)
unnamed: D64.6 (DO), D65.1 (DI)
unnamed: D65.5 (CO), D66.2 (CI)
unnamed: D65.6 (DO), D66.1 (DI)
unnamed: D66.5 (CO), D67.2 (CI)
unnamed: D66.6 (DO), D67.1 (DI)
unnamed: D67.5 (CO), D68.2 (CI)
unnamed: D67.6 (DO), D68.1 (DI)
unnamed: D68.5 (CO), D69.2 (CI)
unnamed: D68.6 (DO), D69.1 (DI)
unnamed: D69.5 (CO), D70.2 (CI)
unnamed: D69.6 (DO), D70.1 (DI)
unnamed: D70.5 (CO), D71.2 (CI)
unnamed: D70.6 (DO), D71.1 (DI)
unnamed: D71.5 (CO), D72.2 (CI)
unnamed: D71.6 (DO), D72.1 (DI)
unnamed: D72.5 (CO), D73.2 (CI)
unnamed: D72.6 (DO), D73.1 (DI)
unnamed: D74.5 (CO), D75.2 (CI)
unnamed: D74.6 (DO), D75.1 (DI)
unnamed: D75.5 (CO), q3 out1.2
unnamed: D75.6 (DO), q3 out1.1
unnamed: D76.5 (CO), D77.2 (CI)
unnamed: D76.6 (DO), D77.1 (DI)
unnamed: D77.5 (CO), D78.2 (CI)
unnamed: D77.6 (DO), D78.1 (DI)
unnamed: D78.5 (CO), D79.2 (CI)
unnamed: D78.6 (DO), D79.1 (DI)
unnamed: D79.5 (CO), D80.2 (CI)
unnamed: D79.6 (DO), D80.1 (DI)
unnamed: D80.5 (CO), D81.2 (CI)
unnamed: D80.6 (DO), D81.1 (DI)
unnamed: D81.5 (CO), D82.2 (CI)
unnamed: D81.6 (DO), D82.1 (DI)
unnamed: D82.5 (CO), D83.2 (CI)
unnamed: D82.6 (DO), D83.1 (DI)
unnamed: D83.5 (CO), D84.2 (CI)
unnamed: D83.6 (DO), D84.1 (DI)
unnamed: D84.5 (CO), D85.2 (CI)
unnamed: D84.6 (DO), D85.1 (DI)
unnamed: D85.5 (CO), D86.2 (CI)
unnamed: D85.6 (DO), D86.1 (DI)
unnamed: D86.5 (CO), D87.2 (CI)
unnamed: D86.6 (DO), D87.1 (DI)
unnamed: D88.5 (CO), D89.2 (CI)
unnamed: D88.6 (DO), D89.1 (DI)
unnamed: D89.5 (CO), D90.2 (CI)
unnamed: D89.6 (DO), D90.1 (DI)
unnamed: D90.5 (CO), D91.2 (CI)
unnamed: D90.6 (DO), D91.1 (DI)
unnamed: D91.5 (CO), D92.2 (CI)
unnamed: D91.6 (DO), D92.1 (DI)
unnamed: D92.5 (CO), D93.2 (CI)
unnamed: D92.6 (DO), D93.1 (DI)
unnamed: D93.5 (CO), D94.2 (CI)
unnamed: D93.6 (DO), D94.1 (DI)
unnamed: D94.5 (CO), D95.2 (CI)
unnamed: D94.6 (DO), D95.1 (DI)
unnamed: D95.5 (CO), D96.2 (CI)
unnamed: D95.6 (DO), D96.1 (DI)
unnamed: D96.5 (CO), D97.2 (CI)
unnamed: D96.6 (DO), D97.1 (DI)
unnamed: D98.5 (CO), D99.2 (CI)
unnamed: D98.6 (DO), D99.1 (DI)
unnamed: D99.5 (CO), D100.2 (CI)
unnamed: D100.5 (CO), D101.2 (CI)
unnamed: D99.6 (DO), D100.1 (DI)
unnamed: D100.6 (DO), D101.1 (DI)
unnamed: D101.5 (CO), D102.2 (CI)
unnamed: D101.6 (DO), D102.1 (DI)
unnamed: D102.5 (CO), D103.2 (CI)
unnamed: D102.6 (DO), D103.1 (DI)
unnamed: D103.5 (CO), D104.2 (CI)
unnamed: D103.6 (DO), D104.1 (DI)
unnamed: D104.5 (CO), D105.2 (CI)
unnamed: D104.6 (DO), D105.1 (DI)
unnamed: D105.5 (CO), D106.2 (CI)
unnamed: D105.6 (DO), D106.1 (DI)
unnamed: D88.2 (CI), D106.5 (CO)
unnamed: D88.1 (DI), D106.6 (DO)
unnamed: D107.2 (CI), D140.5 (CO)
unnamed: D107.5 (CO), D108.2 (CI)
unnamed: D107.1 (DI), D140.6 (DO)
unnamed: D107.6 (DO), D108.1 (DI)
unnamed: D108.5 (CO), D109.2 (CI)
unnamed: D108.6 (DO), D109.1 (DI)
unnamed: D109.5 (CO), D110.2 (CI)
unnamed: D109.6 (DO), D110.1 (DI)
unnamed: D110.5 (CO), D111.2 (CI)
unnamed: D110.6 (DO), D111.1 (DI)
unnamed: D111.5 (CO), D112.2 (CI)
unnamed: D111.6 (DO), D112.1 (DI)
unnamed: D112.5 (CO), D113.2 (CI)
unnamed: D112.6 (DO), D113.1 (DI)
unnamed: D113.5 (CO), D114.2 (CI)
unnamed: D113.6 (DO), D114.1 (DI)
unnamed: D114.5 (CO), D115.2 (CI)
unnamed: D114.6 (DO), D115.1 (DI)
unnamed: D115.5 (CO), D116.2 (CI)
unnamed: D115.6 (DO), D116.1 (DI)
unnamed: D116.5 (CO), D117.2 (CI)
unnamed: D116.6 (DO), D117.1 (DI)
unnamed: D117.5 (CO), D118.2 (CI)
unnamed: D117.6 (DO), D118.1 (DI)
unnamed: D76.2 (CI), D118.5 (CO)
unnamed: D76.1 (DI), D118.6 (DO)
unnamed: D119.2 (CI), D129.5 (CO)
unnamed: D119.5 (CO), D120.2 (CI)
unnamed: D119.1 (DI), D129.6 (DO)
unnamed: D119.6 (DO), D120.1 (DI)
unnamed: D120.5 (CO), D121.2 (CI)
unnamed: D120.6 (DO), D121.1 (DI)
unnamed: D121.5 (CO), D122.2 (CI)
unnamed: D121.6 (DO), D122.1 (DI)
unnamed: D74.2 (CI), D122.5 (CO)
unnamed: D74.1 (DI), D122.6 (DO)
unnamed: D123.2 (CI), D171.5 (CO)
unnamed: D123.5 (CO), D124.2 (CI)
unnamed: D123.1 (DI), D171.6 (DO)
unnamed: D123.6 (DO), D124.1 (DI)
unnamed: D124.5 (CO), D125.2 (CI)
unnamed: D124.6 (DO), D125.1 (DI)
unnamed: D125.5 (CO), D126.2 (CI)
unnamed: D125.6 (DO), D126.1 (DI)
unnamed: D126.5 (CO), D127.2 (CI)
unnamed: D126.6 (DO), D127.1 (DI)
unnamed: D127.5 (CO), D128.2 (CI)
unnamed: D127.6 (DO), D128.1 (DI)
unnamed: D128.5 (CO), D129.2 (CI)
unnamed: D128.6 (DO), D129.1 (DI)
unnamed: D130.2 (CI), D162.5 (CO)
unnamed: D130.5 (CO), D131.2 (CI)
unnamed: D130.1 (DI), D162.6 (DO)
unnamed: D130.6 (DO), D131.1 (DI)
unnamed: D131.5 (CO), D132.2 (CI)
unnamed: D131.6 (DO), D132.1 (DI)
unnamed: D132.5 (CO), D133.2 (CI)
unnamed: D132.6 (DO), D133.1 (DI)
unnamed: D133.5 (CO), D134.2 (CI)
unnamed: D133.6 (DO), D134.1 (DI)
unnamed: D134.5 (CO), D135.2 (CI)
unnamed: D134.6 (DO), D135.1 (DI)
unnamed: D135.5 (CO), D136.2 (CI)
unnamed: D135.6 (DO), D136.1 (DI)
unnamed: D136.5 (CO), D137.2 (CI)
unnamed: D136.6 (DO), D137.1 (DI)
unnamed: D137.5 (CO), D138.2 (CI)
unnamed: D137.6 (DO), D138.1 (DI)
unnamed: D138.5 (CO), D139.2 (CI)
unnamed: D138.6 (DO), D139.1 (DI)
unnamed: D139.5 (CO), D140.2 (CI)
unnamed: D139.6 (DO), D140.1 (DI)
unnamed: D141.2 (CI), D150.5 (CO)
unnamed: D141.5 (CO), D142.2 (CI)
unnamed: D141.1 (DI), D150.6 (DO)
unnamed: D141.6 (DO), D142.1 (DI)
unnamed: D142.5 (CO), D143.2 (CI)
unnamed: D142.6 (DO), D143.1 (DI)
unnamed: D143.5 (CO), D144.2 (CI)
unnamed: D143.6 (DO), D144.1 (DI)
unnamed: D144.5 (CO), D145.2 (CI)
unnamed: D144.6 (DO), D145.1 (DI)
unnamed: D145.5 (CO), D146.2 (CI)
unnamed: D145.6 (DO), D146.1 (DI)
unnamed: D98.2 (CI), D146.5 (CO)
unnamed: D98.1 (DI), D146.6 (DO)
unnamed: D147.2 (CI), Q1 in1.2
unnamed: D147.5 (CO), D195.2 (CI)
unnamed: D147.1 (DI), Q1 in1.1
unnamed: D147.6 (DO), D195.1 (DI)
unnamed: D148.2 (CI), D195.5 (CO)
unnamed: D148.5 (CO), D149.2 (CI)
unnamed: D148.1 (DI), D195.6 (DO)
unnamed: D148.6 (DO), D149.1 (DI)
unnamed: D149.5 (CO), D150.2 (CI)
unnamed: D149.6 (DO), D150.1 (DI)
unnamed: D151.2 (CI), D194.5 (CO)
unnamed: D151.5 (CO), D152.2 (CI)
unnamed: D151.1 (DI), D194.6 (DO)
unnamed: D151.6 (DO), D152.1 (DI)
unnamed: D152.5 (CO), D153.2 (CI)
unnamed: D152.6 (DO), D153.1 (DI)
unnamed: D153.5 (CO), D154.2 (CI)
unnamed: D153.6 (DO), D154.1 (DI)
unnamed: D154.5 (CO), D155.2 (CI)
unnamed: D154.6 (DO), D155.1 (DI)
unnamed: D155.5 (CO), D156.2 (CI)
unnamed: D155.6 (DO), D156.1 (DI)
unnamed: D156.5 (CO), D157.2 (CI)
unnamed: D156.6 (DO), D157.1 (DI)
unnamed: D157.5 (CO), D158.2 (CI)
unnamed: D157.6 (DO), D158.1 (DI)
unnamed: D158.5 (CO), D159.2 (CI)
unnamed: D158.6 (DO), D159.1 (DI)
unnamed: D159.5 (CO), D160.2 (CI)
unnamed: D159.6 (DO), D160.1 (DI)
unnamed: D160.5 (CO), D161.2 (CI)
unnamed: D160.6 (DO), D161.1 (DI)
unnamed: D161.5 (CO), D162.2 (CI)
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

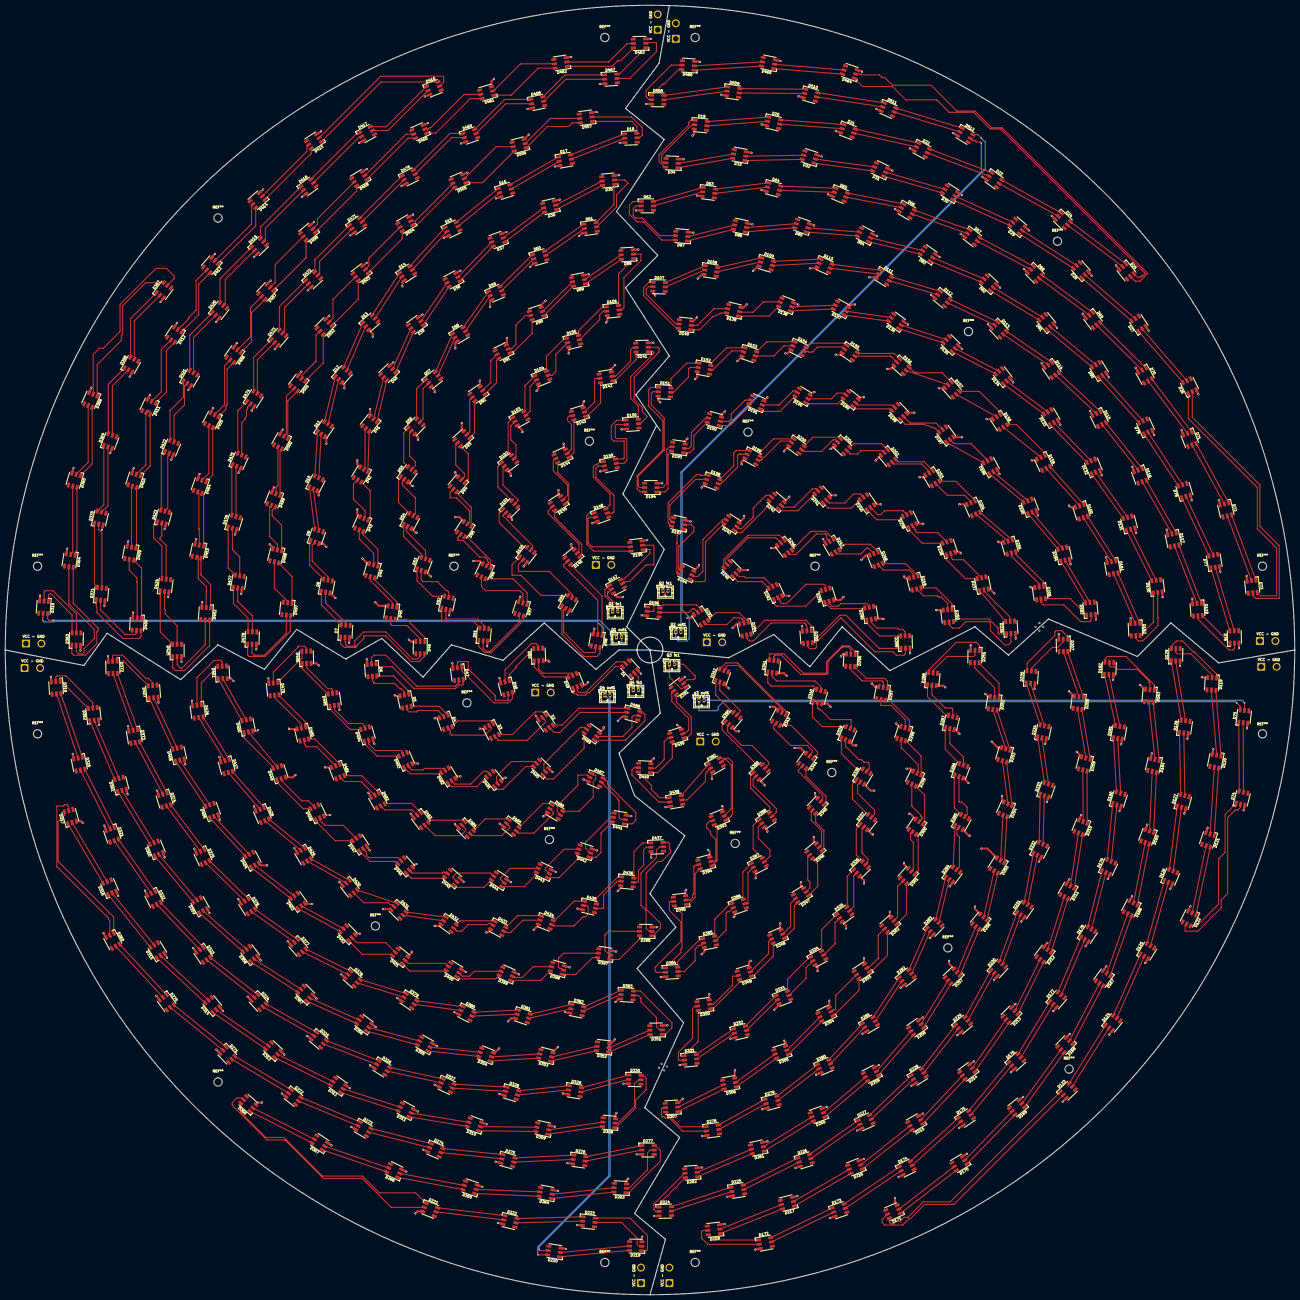
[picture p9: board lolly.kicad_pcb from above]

Board: 2 copper layers, 500.0 x 500.0 mm, 532 parts (0 on the bottom side), 1034 nets.

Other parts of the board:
VCC - GND: SolderWire-1.5sqmm_1x02_P6mm_D1.7mm_OD3mm
VCC - GND#2, VCC - GND#3, VCC - GND#4, VCC - GND#5, VCC - GND#6, VCC - GND#7, VCC - GND#8, VCC - GND#9, VCC - GND#10, VCC - GND#11, VCC - GND#12: SolderWire-1.5sqmm_1x02_P6mm_D1.7mm_OD3mm

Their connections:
GND: VCC - GND.2, VCC - GND#2.2, VCC - GND#3.2, VCC - GND#4.2, VCC - GND#5.2, VCC - GND#6.2, VCC - GND#7.2, VCC - GND#8.2, VCC - GND#9.2, VCC - GND#10.2, VCC - GND#11.2, VCC - GND#12.2; also elsewhere on the board
VCC: VCC - GND.1, VCC - GND#2.1, VCC - GND#3.1, VCC - GND#4.1, VCC - GND#5.1, VCC - GND#6.1, VCC - GND#7.1, VCC - GND#8.1, VCC - GND#9.1, VCC - GND#10.1, VCC - GND#11.1, VCC - GND#12.1; also elsewhere on the board

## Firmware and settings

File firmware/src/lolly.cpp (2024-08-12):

// #define FASTLED_ALLOW_INTERRUPTS 0

#include <Arduino.h>
#include <Audio.h>
#include <ADC.h>
#include <SoftwareSerial.h>
#include <FastLED.h>
#include <Adafruit_Sensor.h>
#include <Adafruit_BNO055.h>
#include <Adafruit_NeoTrellis.h>
#include <Adafruit_NeoPixel.h>
#include <Wire.h>
// #include <Adafruit_SH110X.h>
#include <math.h>
#include <RCSwitch.h>
#include <vector>

#define ARRAY_SIZE(A) (sizeof(A) / sizeof((A)[0]))

#define POTENTIOMETER_PIN A17
#define MIC_PIN A2
#define REMOTE_RECEIVER_PIN 24

#define INPUT_CONTROLLER_I2C_ADDRESS 0x42

// analog - digital
ADC *adc = new ADC();

// remote codes
#define REMOTE_BUTTON_A 240191
#define REMOTE_BUTTON_B 4382
#define REMOTE_BUTTON_C 4242
#define REMOTE_BUTTON_D 987654

// remote switch 433 Mhz
RCSwitch remoteSwitch = RCSwitch();

// motion sensor
Adafruit_BNO055 bno = Adafruit_BNO055(-1, 0x29, &Wire2);

// Display
#define SCREEN_I2C_ADDRESS 0x3C // I2C address of the Amazon OLED display, even though it says 0x78 on the back
#define SCREEN_WIDTH 128        // OLED display width, in pixels
#define SCREEN_HEIGHT 64        // OLED display height, in pixels
#define OLED_RESET -1           //   QT-PY / XIAO
// Adafruit_SH1106G display = Adafruit_SH1106G(SCREEN_WIDTH, SCREEN_HEIGHT, &Wire1, OLED_RESET);

// button board
// for SCA/SCl might have to use &Wire1

// active or not active for the pad buttons
// uint8_t buttonState[16] = {0, 0, 0, 0, 0, 0, 0, 0, 0, 0, 0, 0, 0, 0, 0, 0};
// uint8_t buttonStateful[16] = {0, 0, 0, 1, 0, 0, 0, 1, 0, 0, 0, 0, 0, 0, 0, 0};
// uint32_t buttonDebounce[16] = {0, 0, 0, 1, 0, 0, 0, 1, 0, 0, 0, 0, 0, 0, 0, 0};

#define NUM_LEDS 512
#define MAX_BRIGHTNESS 100
// #define MAX_BRIGHTNESS 150
#define TEENSY_LED 13

// 2,14,7,8  ,6,20,21,5
CRGB _leds[NUM_LEDS]; // actual rendered leds - filled by remap
CRGB leds[NUM_LEDS];  // leds to work with while codeing effects

AudioInputAnalog adc1(MIC_PIN);
AudioAnalyzePeak peak1;
AudioConnection patchCord1(adc1, peak1);

#include "segment.h"
#include "maps.h"
#include "palette.h"

// global state
int8_t currentMode = 0;
int8_t previousMode = 0;
int8_t nextScheduledMode = -1;
int8_t nextScheduledModeDir = 0;
// uint8_t currentBrightness = MAX_BRIGHTNESS;
uint8_t currentBrightness = 25;
uint16_t currentDelay = 0; // delay between frames
uint8_t shouldClear = 1;   // clear all leds between frames
uint8_t shouldShow = 1;

// Debug stuff to count LEDS properly
static int globalP = 0;

int accelTestMV = 0;

elapsedMillis fps0;

byte buttonState = 0;
byte buttonDebounce = 0;
byte leftEncoder = 0;
byte rightEncoder = 0;

// base class to create some effects
class Effect
{
public:
  virtual void setup(void) {};
  virtual void draw(void) {};
};

std::vector<Effect *> effects;

#include "inc/util.cpp"

// map from linear leds to the actual physical led order
// _leds is the array that fastled uses for physical signals
void remap()
{
  // return;
  for (int i = 0; i < NUM_LEDS; i++)
  {
    _leds[ledsOnPCBMap[i]] = leds[i];
  }
}

void checkSerial()
{
  if (Serial.available() > 0)
  {
    char c = Serial.read();
    if (c == 'n')
      nextMode(1);
    else if (c == 'b')
      nextMode(-1);
    else
    {
      globalP++;
      Serial.print("POS:");
      Serial.println(globalP);
    }
  }
}

void readFromInputController()
{
  Wire1.requestFrom(INPUT_CONTROLLER_I2C_ADDRESS, 6);
  // Serial.print("read from input controller: read");

  int i = 0;
  // byte buttonState = 0;
  // int leftEncoder = 0;
  // int rightEncoder = 0;
  while (Wire1.available())
  { // slave may send less than requested

    char b = Wire1.read();

    int a4 = 0;
    int a5 = 0;
    int a6 = 0;

    switch (i)
    {
    case 0:
      buttonState = b;
      break;
    // case 1:
    //   // buttonState |= b << 8;
    //   break;
    case 2:
      leftEncoder = b;
      break;
    // case 2:
    //   leftEncoder |= b << 8;
    //   break;
    case 3:
      rightEncoder = b;
      break;
    case 4:
      a4 = b;
      break;
    case 5:
      a5 = b;
      break;
    case 6:
      a6 = b;
      break;
      //   rightEncoder |= b << 8;
      //   break;
    }

    i++;
    if (i == 6)
    {
      // Serial.print(i);
      // Serial.print(" bytes. buttons: ");
      // Serial.print(buttonState, BIN);
      // Serial.print(" left: ");
      // Serial.print(leftEncoder);
      // Serial.print(" right: ");
      // Serial.print(rightEncoder);
      // Serial.print(" a4: ");
      // Serial.print(a4);
      // Serial.print(" a5: ");
      // Serial.print(a5);
      // Serial.print(" a6: ");
      // Serial.println(a6);

      break;
    }
  }
}

void runScheduluer()
{
  if (nextScheduledMode != -1)
  {
    setMode(nextScheduledMode);
    nextScheduledMode = -1;
  }
  if (nextScheduledModeDir)
  {
    nextMode(nextScheduledModeDir);
    nextScheduledModeDir = 0;
  }
}

uint16_t fps = 0;

void showFps()
{
  Serial.print("FPS: ");
  Serial.println(fps);
  fps = 0;
}

// 2d coordiante system effects similar to PixelBlaze, just derive an effect
class Effect2D : public Effect
{
public:
  virtual void setup(void) {};
  void draw(void) override
  {
    this->beforeRender();
    for (int i = 0; i < NUM_LEDS; i++)
    {
      leds[i] = this->render(i, ledsXYMap[i][0], ledsXYMap[i][1]);
    }
  };
  virtual void beforeRender(void) {};
  virtual CRGB render(int idx, float x, float y) { return CRGB::Black; }
};

// instead of 2d cartesian this is a polar coordinate system
class EffectPolar : public Effect
{
public:
  virtual void setup(void) {};
  void draw(void) override
  {
    this->beforeRender();
    for (int i = 0; i < NUM_LEDS; i++)
    {
      leds[i] = this->render(i, ledsPolarMap[i][0], ledsPolarMap[i][1]);
    }
  };
  virtual void beforeRender(void) {};
  virtual CRGB render(int idx, float r, float deg) { return CRGB::Black; }
};

uint16_t BNO055_SAMPLERATE_DELAY_MS = 10;
// velocity = accel*dt (dt in seconds)
// position = 0.5*accel*dt^2
double ACCEL_VEL_TRANSITION = (double)(BNO055_SAMPLERATE_DELAY_MS) / 1000.0;
double ACCEL_POS_TRANSITION = 0.5 * ACCEL_VEL_TRANSITION * ACCEL_VEL_TRANSITION;
double DEG_2_RAD = 0.01745329251; // trig functions require radians, BNO055 outputs degrees

// trait to add accelerometer data to an effect
class AccelTrait
{
private:
  elapsedMillis t;

public:
  double xPos = 0;
  double yPos = 0;
  double headingVel = 0;
  sensors_event_t orientationData, linearAccelData, accelData;

  void updateSenorData()
  {
    // - VECTOR_ACCELEROMETER - m/s^2
    // - VECTOR_MAGNETOMETER  - uT
    // - VECTOR_GYROSCOPE     - rad/s
    // - VECTOR_EULER         - degrees
    // - VECTOR_LINEARACCEL   - m/s^2
    // - VECTOR_GRAVITY       - m/s^2
    if (this->t < BNO055_SAMPLERATE_DELAY_MS)
      return;
    this->t = 0;

    bno.getEvent(&this->orientationData, Adafruit_BNO055::VECTOR_EULER);
    //  bno.getEvent(&angVelData, Adafruit_BNO055::VECTOR_GYROSCOPE);
    bno.getEvent(&this->linearAccelData, Adafruit_BNO055::VECTOR_LINEARACCEL);
    bno.getEvent(&this->accelData, Adafruit_BNO055::VECTOR_ACCELEROMETER);

    this->xPos = this->xPos + ACCEL_POS_TRANSITION * this->linearAccelData.acceleration.x;
    this->yPos = this->yPos + ACCEL_POS_TRANSITION * this->linearAccelData.acceleration.y;

    // velocity of sensor in the direction it's facing
    this->headingVel = ACCEL_VEL_TRANSITION * this->linearAccelData.acceleration.x / cos(DEG_2_RAD * this->orientationData.orientation.x);
  }
};

void printBNOCalibrationStatus()
{
  uint8_t sensorStatus[4] = {0, 0, 0, 0};
  bno.getCalibration(&sensorStatus[0], &sensorStatus[1], &sensorStatus[2], &sensorStatus[3]);
  if (!sensorStatus[0])
  {
    Serial.print("SYSTEM CALIBRATION NOT READY");
  }
  Serial.print("Sys:");
  Serial.print(sensorStatus[0]);
  Serial.print(" G:");
  Serial.print(sensorStatus[1]);
  Serial.print(" A:");
  Serial.print(sensorStatus[2]);
  Serial.print(" M:");
  Serial.println(sensorStatus[3]);
}

class PolarTest : public EffectPolar
{
  float r = 0;
  uint8_t hue = 0;
  void beforeRender() override
  {
    this->r = beatsin8(140, 0, 255) / 255.0;
    this->hue++;
  }
  CRGB render(int idx, float r, float deg) override
  {
    float delta = abs(r - this->r);
    if (delta < 0.2)
      return CHSV(this->hue, 200 - (0.2 - delta) * 600, 200);
    return CRGB::Black;
  }
};

class VariableArmsDemo : public Effect
{
  void draw(void) override
  {
    static uint8_t hueOffset = 0;
    static uint8_t numArms = 1;
    // EVERY_N_SECONDS(1) { numArms++; }
    EVERY_N_MILLIS(2) { hueOffset++; }
    EVERY_N_MILLIS(5000) { numArms++; }
    for (int i = 0; i < NUM_LEDS; i++)
    {
      uint16_t armIndex = i % numArms;
      uint8_t hue = (map(armIndex, 0, numArms, 0, 255) + hueOffset) % 255;
      leds[ledsAsSpiralMap[i]] = CHSV(hue, 255, 255);
    }
  }
};

// uses the planar map instead of x and y coordinates of every pixel
class PlanarDemo : public Effect
{
  void draw(void) override
  {
    for (int i = 0; i < PLANAR_COLS; i++)
    {
      for (int j = 0; j < PLANAR_ROWS; j++)
      {
        int idx = planarMap[i * PLANAR_COLS + j];
        if (idx == 1000)
          continue;
        leds[idx] = CHSV(i * 20, 255, 255);
      }
    }
  }
};

// uses the polarMap instead of distance and angle of every pixel
class PolarDemo : public Effect
{
  void draw(void) override
  {
    uint16_t a = millis() / 4;
    static int n = 0;

    for (int j = 0; j < POLAR_ROWS; j++)
    {
      for (int i = 0; i < POLAR_COLS; i++)
      {
        uint16_t idx = polarMap[POLAR_COLS * j + i];
        if (idx == 1000)
          continue;
        leds[idx].setHue(i * 54 + (a >> 2) + (sin8(j * 16 + a)) >> 1);
      }
    }
  }
};

class PolarCaleidoscope : public Effect
{
  void draw(void) override
  {
    uint16_t a = millis() / 4;
    static int n = 0;
    for (int j = 0; j < POLAR_ROWS; j++)
    {
      for (int i = 0; i < POLAR_COLS; i++)
      {
        uint16_t idx = polarMap[POLAR_COLS * j + i];

        if (idx == 1000)
          continue;

        byte r = (sin8(i * 16 + a) + cos8(j * 16 + a / 2)) / 2;
        byte g = sin8(j * 16 + a / 2 + sin8(leds[idx].r + a) / 16);
        byte b = cos8(i * 16 + j * 16 - a / 2 + leds[idx].g);

        leds[idx].setRGB(r, g, b);
      }
    }
  }
};
class PolarCaleidoscope2 : public Effect
{
  void draw(void) override
  {
    uint16_t a = millis() / 3;
    static int n = 0;
    for (int j = 0; j < POLAR_ROWS; j++)
    {
      for (int i = 0; i < POLAR_COLS; i++)
      {
        uint16_t idx = polarMap[POLAR_COLS * j + i];

        if (idx == 1000)
          continue;

        byte r = (sin8(i * 28 + a) + cos8(j * 28 + a)) >> 1;
        byte g = (sin8(i * 28 - a) + cos8(j * 28 + a >> 1)) >> 1;
        byte b = sin8(j * 26 + a);

        leds[idx].setRGB(r, g, b);
      }
    }
  }
};

class PolarFireFly : public Effect
{
  void draw(void) override
  {
    uint16_t a = millis() / 2;
    static int n = 0;
    for (int j = 0; j < POLAR_ROWS; j++)
    {
      for (int i = 0; i < POLAR_COLS; i++)
      {
        uint16_t idx = polarMap[POLAR_COLS * j + i];

        int jj = POLAR_ROWS - j;

        if (idx == 1000)
          continue;
        leds[idx] = HeatColor(qsub8(inoise8(i * 60 + a, jj * 5 + a, a / 3), abs8(jj - (POLAR_ROWS - 1)) * 255 / (POLAR_ROWS + 2)));
      }
    }
  }
};

class DiagonalSin : public Effect2D
{

  virtual CRGB render(int idx, float x, float y)
  {
    return CHSV(x * 100 + (sin8(y * PI * 2 * 255) / 255.0) * y * 100 + millis() / 8, 200, 200);
  }
};

class SinelonEffect : public Effect
{
public:
  void setup()
  {
    shouldClear = false;
  }

  void draw()
  {
    static uint8_t gHue = 0;
    fadeToBlackBy(leds, NUM_LEDS, 20);

    int pos = beatsin16(map(80, 0, 255, 2, 60), 0, NUM_LEDS);
    leds[pos] += CHSV(gHue, 255, 192);
    EVERY_N_MILLISECONDS(3) { gHue++; }
  }
};

class FTest : public Effect
{
public:
  void draw()
  {
    static uint8_t x = 0;
    x++;
    // fill_rainbow(leds, NUM_LEDS, x, 1);
    fill_solid(_leds, 128, CRGB::Green);
    fill_solid(&_leds[128], 128, CRGB::Red);
    fill_solid(&_leds[128 + 128], 127, CRGB::Blue);
    fill_solid(&_leds[128 + 128 + 127], 129, CRGB::Yellow);
  }
};
class MapTest : public Effect
{
public:
  void draw()
  {
    static uint16_t x = 0;

    leds[x] = CRGB::Red;
    x++;
    x = x % NUM_LEDS;
    delay(500);
  }
};

class ColorWheelWithSparkels : public Effect
{
public:
  void setup()
  {
    currentDelay = 0;
    shouldClear = false;
  }
  void draw()
  {
    static elapsedMillis timer;
    if (timer < 20)
      return;
    timer = 0;

    static uint8_t hue = 0;
    hue++;

    hue++;
    for (int i = 0; i < NUM_LEDS; i++)
    {
      leds[i] = CHSV(5 * i + hue, 240, 150);
    }
    for (int j = 0; j < 3; j++)
    {
      int x = random(0, NUM_LEDS);
      leds[x] = CRGB::White;
    }
  }
};

class AccelTest : public Effect, public AccelTrait
{
public:
  void setup()
  {
    shouldClear = false;
  }

  void draw()
  {
    // fadeToBlackBy(leds, NUM_LEDS, 13);
    this->updateSenorData();
    EVERY_N_MILLISECONDS(250)
    {
      Serial.print("Heading: ");
      Serial.println(this->orientationData.orientation.x);
      // Serial.print("Position: ");
      // Serial.print(xPos);
      // Serial.print(" , ");
      // Serial.println(yPos);
      // Serial.print("Speed: ");
      // Serial.println(headingVel);
      Serial.print("linearAccel");
      Serial.print(" x:");
      Serial.print(this->linearAccelData.acceleration.x);
      Serial.print(" y:");
      Serial.print(this->linearAccelData.acceleration.y);
      Serial.print(" z:");
      Serial.println(this->linearAccelData.acceleration.z);
      // Serial.println("accel");
      // this->printEvent(&accelData);
      // Serial.println("-------");
    }
  }
};

class AudioTest : public Effect
{

  elapsedMillis fps;
  void draw() override
  {
    if (this->fps > 24)
    {
      if (peak1.available())
      {
        this->fps = 0;
        int monoPeak = peak1.read() * 30.0;
        Serial.print("|");
        for (int cnt = 0; cnt < monoPeak; cnt++)
        {
          Serial.print(">");
        }
        Serial.println();
      }
    }
  }
};
// class GifTest : public Effect
// {
//   void draw(void) override
//   {

//     CRGB *pal = (CRGB *)status->palette;
//     uint8_t *pixels = status->hsd.buffers + HEATSHRINK_STATIC_INPUT_BUFFER_SIZE;
//     // plot each sprite pixel modulo the size of the matrix, i.e. wrap the image
//     for (int i = 0; i < PLANAR_COLS; i++)
//     {
//       for (int j = 0; j < PLANAR_ROWS; j++)
//       {
//         int idx = planarMap[i * PLANAR_COLS + j];
//         if (idx == 1000)
//           continue;

//         uint8_t palette_index = *pixels++;
//         if (palette_index > 0 && cfg.effect != 1)
//         {
//           // non-0 palette entry;  copy the palette entry to the LED
//           leds[idx] = pal[palette_index];
//         }
//         else
//         {
//           // palette entry 0 is the mask;  fade this LED to the mask colour (black usually)
//           fadeTowardColour(leds[idx], pal[palette_index], fade_speed);
//         }
//       }
//     }
//   }
// };

DEFINE_GRADIENT_PALETTE(bla){
    0, 194, 1, 1,
    94, 1, 29, 18,
    132, 57, 131, 28,
    255, 113, 1, 1};

class Tunnel : public Effect
{
  void setup() override
  {
    shouldClear = true;
  }
  void draw(void) override
  {
    int t = millis() >> 3;
    currentPalette = bla;
    for (int i = 0; i < PLANAR_COLS; i++)
    {
      for (int j = 0; j < PLANAR_ROWS; j++)
      {
        int idx = planarMap[i * PLANAR_COLS + j];
        if (idx == 1000)
          continue;

        uint16_t colorIdx = sqrt16((i -= sin8(i + t / 3) >> 4) * i + (j -= cos8(j + t >> 1) >> 4) * j) * 24 - t * 2;
        CRGB newcolor = ColorFromPalette(currentPalette, colorIdx, 255);
        leds[idx] = newcolor;
        // nblend(leds[idx], newcolor, 32);
      }
    }
  }
};

// void Flower() {
//   uint16_t  a = millis()/8;

//   for (int j = 0; j < NUM_ROWS_CILINDR; j++) {
//     for (int i = 0; i < NUM_COLS_CILINDR; i++) {
//       uint16_t index = XY_CILINDR(i,j);
//       if (index==lastSafeIndex) continue;
//       CRGB newcolor = ColorFromPalette( gCurrentPalette, (j*255/(NUM_ROWS_CILINDR-1)+sin8((i*8+a))+sin8(i*30-a)+a)/2, 255);
//       nblend (leds[index], newcolor, 16);
//     }
//   }
// }

// void DiagonalPattern() {
//  uint16_t ms = millis()/8;
//  int index=0;

//   for (byte j = 0; j < NUM_ROWS_PLANAR; j++) {
//     for (byte i = 0; i < NUM_COLS_PLANAR; i++) {
//       int ledsindex = XY_fibon_PLANAR(i,j);
//       if (ledsindex==lastSafeIndex) continue;
//       leds[ledsindex].setHue((i<<3)+(j<<3)+ms);
//     }
//   }
// }

class Diagonal : public EffectPolar
{

  virtual CRGB render(int idx, float x, float y)
  {
    return CHSV(x * 100 + y * 100 + millis() / 8, 200, 200);
  }
};

class Blabla : public EffectPolar
{
  uint8_t hue = 0;
  void beforeRender() override
  {
    this->hue++;
  }
  CRGB render(int idx, float r, float deg) override
  {
    if (r < 0.1)
      return CHSV(this->hue, 200, 200);
    return CRGB::Black;
  }
};

class Swirl : public Effect
{

  void setup() override
  {
    shouldClear = false;
  }

  void draw(void) override
  {
    uint16_t a = millis() / 7;
    static int n = 0;

    for (int j = 0; j < POLAR_ROWS; j++)
    {
      for (int i = 0; i < POLAR_COLS; i++)
      {
        uint16_t idx = polarMap[POLAR_COLS * j + i];
        if (idx == 1000)
          continue;

        byte hue = i * 56 + (a >> 2) + (sin8(j * 16 + a)) >> 1;
        nblend(leds[idx], ColorFromPalette(currentPalette, hue, 255), 16);
      }
    }
  }
};

// RGBTunnel
//     Flower
//         colorwaves
//             DiagonalPattern
//                 Spiral2
//                     RGB_Caleidoscope2
//                         RGB_Caleidoscope1

//                                 RGB_hiphotic

// the setup routine runs once when you press reset:
void setup()
{
  // add all effects
  effects = {
      // new FirstEffect(),
      new PolarFireFly(),
      new SinelonEffect(),
      // new Blabla(),
      new VariableArmsDemo(),
      new PolarCaleidoscope(),
      new PolarCaleidoscope2(),
      // new MapTest(),
      new PolarTest(),
      // new FTest(),
      new PolarDemo(),
      new Diagonal(),
      new DiagonalSin(),
      // new AudioTest(),
      // new AccelTest(),
      new ColorWheelWithSparkels(),
  };

  while (!Serial && (millis() <= 2000))
    ; // Wait for Serial interface
  Serial.begin(115200);
  Wire1.begin(); // join I2C bus as master

  Serial.println("boot lolly");

  Serial.println("LED init");

  // 2,14,7,8,6, 20,21,5 (last three are unused now)
  // 5 = 26 due to pin changes
  FastLED.addLeds<APA102, 2, 14, BGR>(_leds, 128);
  FastLED.addLeds<APA102, 20, 14, BGR>(_leds, 128, 128);
  FastLED.addLeds<APA102, 21, 14, BGR>(_leds, 128 + 128, 127);
  FastLED.addLeds<APA102, 26, 14, BGR>(_leds, 128 + 128 + 127, 129);

  FastLED.setMaxPowerInVoltsAndMilliamps(5, 5000);
  FastLED.setBrightness(MAX_BRIGHTNESS);

  // init radio!
  Serial.println("Radio init");
  pinMode(REMOTE_RECEIVER_PIN, INPUT);
  remoteSwitch.enableReceive(REMOTE_RECEIVER_PIN);

  // Initialise the motion sensor
  Serial.println("motion init");
  if (!bno.begin())
  {
    Serial.print("motion sensor error");
  }
  else
  {
    Serial.println("motion sensor OK");
    delay(200);
    int8_t temp = bno.getTemp();
    Serial.print("temperature: ");
    Serial.print(temp);
    Serial.println(" C");
    bno.setExtCrystalUse(true);

    printBNOCalibrationStatus();
  }

  // init audio
  AudioMemory(8);

  pinMode(TEENSY_LED, OUTPUT);
  pinMode(POTENTIOMETER_PIN, INPUT);

  // adc->setAveraging(16, ADC_1);
  // adc->setResolution(16, ADC_1);
  // adc->setConversionSpeed(ADC_CONVERSION_SPEED::VERY_LOW_SPEED, ADC_1);
  // adc->setSamplingSpeed(ADC_SAMPLING_SPEED::MED_SPEED, ADC_1);
  // // adc->setReference(ADC_REFERENCE::REF_1V2, ADC_0);
  // adc->setReference(ADC_REFERENCE::REF_3V3, ADC_1); // doesn't work but we hacked the audio library and core to still  work
  // adc->adc1->recalibrate();

  delay(10);

  // start with mode number 0
  effects[currentMode]->setup();

  // set a global pallette
  currentPalette = gradientPalettes[1];
}

bool button1 = false;

void checkButtons()
{
  button1 = false;

  if (buttonState & 1 == 1)
  {
    buttonDebounce = 1;
  }
  if (((buttonState & 1) == 0) && ((buttonDebounce & 1) == 1))
  {
    Serial.println("deounce");
    button1 = true;
    buttonDebounce &= 0xb11111110;
  }

  if (button1)
    nextMode(1);

  currentBrightness = leftEncoder % MAX_BRIGHTNESS;
  if (currentBrightness < 5)
    currentBrightness = 5;
}

void loop()
{
  // EVERY_N_MILLIS(2000) { printBNOCalibrationStatus(); }

  EVERY_N_MILLISECONDS(50)
  {
    readFromInputController();
    checkButtons();
  }

  runScheduluer();

  if (shouldClear)
    clear();

  effects[currentMode]->draw();

  if (shouldShow)
  {
    FastLED.setBrightness(currentBrightness);
    remap();
    FastLED.show();
  }

  fps++;

  EVERY_N_MILLISECONDS(1000) { testled(); }
  EVERY_N_MILLISECONDS(100) { checkSerial(); }
  EVERY_N_MILLISECONDS(1000) { showFps(); }

  if (currentDelay > 0)
    delay(currentDelay);
}

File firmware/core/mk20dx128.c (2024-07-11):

/* Teensyduino Core Library
 * http://www.pjrc.com/teensy/
 * Copyright (c) 2017 PJRC.COM, LLC.
 *
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
 * 2. If the Software is incorporated into a build system that allows
 * selection among a list of target devices, then similar target
 * devices manufactured by PJRC.COM must be included in the list of
 * target devices and selectable in the same manner.
 *
 * THE SOFTWARE IS PROVIDED "AS IS", WITHOUT WARRANTY OF ANY KIND,
 * EXPRESS OR IMPLIED, INCLUDING BUT NOT LIMITED TO THE WARRANTIES OF
 * MERCHANTABILITY, FITNESS FOR A PARTICULAR PURPOSE AND
 * NONINFRINGEMENT. IN NO EVENT SHALL THE AUTHORS OR COPYRIGHT HOLDERS
 * BE LIABLE FOR ANY CLAIM, DAMAGES OR OTHER LIABILITY, WHETHER IN AN
 * ACTION OF CONTRACT, TORT OR OTHERWISE, ARISING FROM, OUT OF OR IN
 * CONNECTION WITH THE SOFTWARE OR THE USE OR OTHER DEALINGS IN THE
 * SOFTWARE.
 */

#include "kinetis.h"
#include "core_pins.h" // testing only
#include "ser_print.h" // testing only
#include <errno.h>


// Flash Security Setting. On Teensy 3.2, you can lock the MK20 chip to prevent
// ( The same applies to the Teensy 3.5 and Teensy 3.6 for their processors )
// anyone from reading your code.  You CAN still reprogram your Teensy while
// security is set, but the bootloader will be unable to respond to auto-reboot
// requests from Arduino. Pressing the program button will cause a full chip
// erase to gain access, because the bootloader chip is locked out.  Normally,
// erase occurs when uploading begins, so if you press the Program button
// accidentally, simply power cycling will run your program again.  When
// security is locked, any Program button press causes immediate full erase.
// Special care must be used with the Program button, because it must be made
// accessible to initiate reprogramming, but it must not be accidentally
// pressed when Teensy Loader is not being used to reprogram.  To set lock the
// security change this to 0xDC.  Teensy 3.0 and 3.1 do not support security lock.
#define FSEC 0xDE

// Flash Options
#define FOPT 0xF9


extern unsigned long _stext;
extern unsigned long _etext;
extern unsigned long _sdata;
extern unsigned long _edata;
extern unsigned long _sbss;
extern unsigned long _ebss;
extern unsigned long _estack;
//extern void __init_array_start(void);
//extern void __init_array_end(void);



extern int main (void);
void ResetHandler(void);
void _init_Teensyduino_internal_(void) __attribute__((noinline));
void __libc_init_array(void);


void fault_isr(void)
{
#if 0
	uint32_t addr;

	SIM_SCGC4 |= 0x00000400;
	UART0_BDH = 0;
	UART0_BDL = 26; // 115200 at 48 MHz
	UART0_C2 = UART_C2_TE;
	PORTB_PCR17 = PORT_PCR_MUX(3);
	ser_print("\nfault: \n??: ");
        asm("ldr %0, [sp, #52]" : "=r" (addr) ::);
        ser_print_hex32(addr);
        ser_print("\n??: ");
        asm("ldr %0, [sp, #48]" : "=r" (addr) ::);
        ser_print_hex32(addr);
        ser_print("\n??: ");
        asm("ldr %0, [sp, #44]" : "=r" (addr) ::);
        ser_print_hex32(addr);
        ser_print("\npsr:");
        asm("ldr %0, [sp, #40]" : "=r" (addr) ::);
        ser_print_hex32(addr);
        ser_print("\nadr:");
        asm("ldr %0, [sp, #36]" : "=r" (addr) ::);
        ser_print_hex32(addr);
        ser_print("\nlr: ");
        asm("ldr %0, [sp, #32]" : "=r" (addr) ::);
        ser_print_hex32(addr);
        ser_print("\nr12:");
        asm("ldr %0, [sp, #28]" : "=r" (addr) ::);
        ser_print_hex32(addr);
        ser_print("\nr3: ");
        asm("ldr %0, [sp, #24]" : "=r" (addr) ::);
        ser_print_hex32(addr);
        ser_print("\nr2: ");
        asm("ldr %0, [sp, #20]" : "=r" (addr) ::);
        ser_print_hex32(addr);
        ser_print("\nr1: ");
        asm("ldr %0, [sp, #16]" : "=r" (addr) ::);
        ser_print_hex32(addr);
        ser_print("\nr0: ");
        asm("ldr %0, [sp, #12]" : "=r" (addr) ::);
        ser_print_hex32(addr);
        ser_print("\nr4: ");
        asm("ldr %0, [sp, #8]" : "=r" (addr) ::);
        ser_print_hex32(addr);
        ser_print("\nlr: ");
        asm("ldr %0, [sp, #4]" : "=r" (addr) ::);
        ser_print_hex32(addr);
        ser_print("\n");
        asm("ldr %0, [sp, #0]" : "=r" (addr) ::);
#endif
	while (1) {
		// keep polling some communication while in fault
		// mode, so we don't completely die.
		if (SIM_SCGC4 & SIM_SCGC4_USBOTG) usb_isr();
		if (SIM_SCGC4 & SIM_SCGC4_UART0) uart0_status_isr();
		if (SIM_SCGC4 & SIM_SCGC4_UART1) uart1_status_isr();
		if (SIM_SCGC4 & SIM_SCGC4_UART2) uart2_status_isr();
	}
}

void unused_isr(void)
{
	fault_isr();
}

void nmi_isr(void)		__attribute__ ((weak, alias("unused_isr")));
void hard_fault_isr(void)	__attribute__ ((weak, alias("fault_isr")));
void memmanage_fault_isr(void)	__attribute__ ((weak, alias("fault_isr")));
void bus_fault_isr(void)	__attribute__ ((weak, alias("fault_isr")));
void usage_fault_isr(void)	__attribute__ ((weak, alias("fault_isr")));
void svcall_isr(void)		__attribute__ ((weak, alias("unused_isr")));
void debugmonitor_isr(void)	__attribute__ ((weak, alias("unused_isr")));
void pendablesrvreq_isr(void)	__attribute__ ((weak, alias("unused_isr")));
void systick_isr(void);
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

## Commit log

2024-06-13 get started
    [lolly-temp.kicad_pcb, lolly.kicad_pcb, lolly.kicad_sch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]
2024-07-05 add v0 schema
    [lolly.kicad_pcb, lolly.kicad_sch, q1.kicad_pcb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]
2024-07-11 reorg and add firmware
    [lolly-temp.kicad_pcb, lolly.kicad_pcb, lolly.kicad_sch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]
2024-07-18 I2C communication with input controller box, doesn't work yet
    [lolly.cpp]
2025-07-09 add new main board
    [core.kicad_pcb, core.kicad_sch]
